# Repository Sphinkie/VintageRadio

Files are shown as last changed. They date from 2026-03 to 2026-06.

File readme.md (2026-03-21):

# VintageRadio pour Raspberry

> work in progress

## Description 

A command-line python program for RaspberryPi that plays music served by a DLNA NAS (Synology).

Faire CTRL-C pour stopper

En mode terminal: 
- n = next song
- b = play again the same song
- d = redo a DLNA server discovery
- q = quit

## Utilisation de Raspberry:

- Apairer la sortie audio avec une enceinte bluetooth si souhaité.

# Roadmap

- Bouton ON/OFF + VOLUME
- Bouton SUIVANT (right) / ENCORE (left) / STAR ME (push)
- Rotatif MODE: GENRE - ANNEE - FAV - ALEA (+ BEAT ?)
- Rotatif SOURCE : LOCAL - NAS
- Tuning GENRE: CLASSIQUES .. BLUES .. JAZZ .. FOLK .. ROCK N'ROLL .. ROCK .. CHANSONS .. MUS.MONDE .. AUTRES
- Tuning ANNEE: 1700 1800 1900  40's 50's 60's 70's 80's 2000
- Tuning FAV:   -      ☆   ☆☆   ☆☆☆   ☆☆☆☆   ☆☆☆☆☆

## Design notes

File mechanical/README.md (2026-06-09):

# Vintage Radio — Modèles 3D

Vue d'ensemble du boîtier :

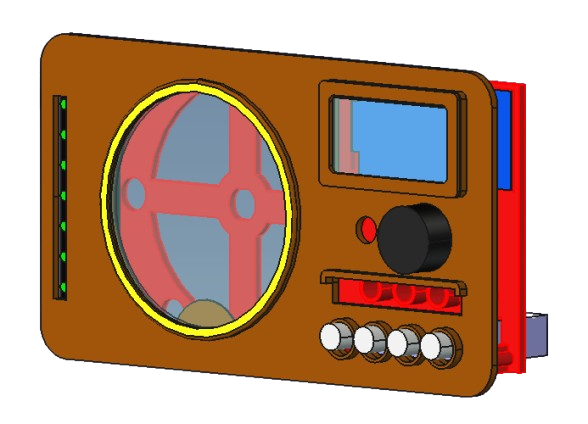
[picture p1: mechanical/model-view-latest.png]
Vue d'ensemble


---
## Conseils d'impression

- Activer le body
- Se mettre en vue ortho
- Menu: affichage -> représentation -> (3) filaire
- Menu: fichier -> Imprimer -> Préférences -> Paysage + A4 + Encre noire uniquement.  
On a alors une mise à l'échelle proche de 1:1.

## Pièces imprimables

### Face avant

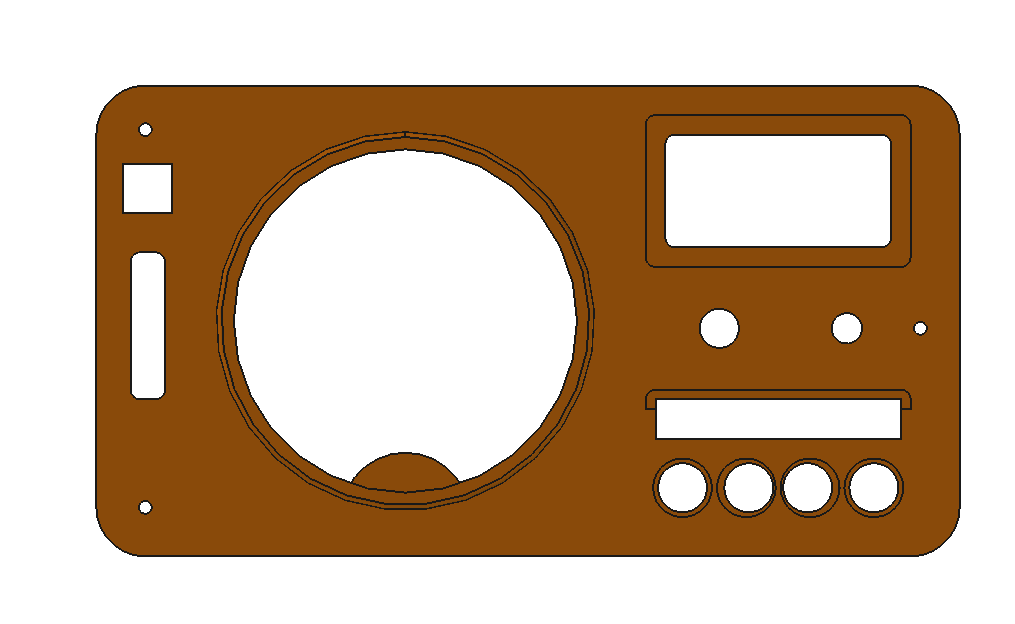
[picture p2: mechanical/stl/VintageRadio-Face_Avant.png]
Face avant


Fichier : [`VintageRadio-Face_Avant.stl`](stl/VintageRadio-Face_Avant.stl)

---

### Support

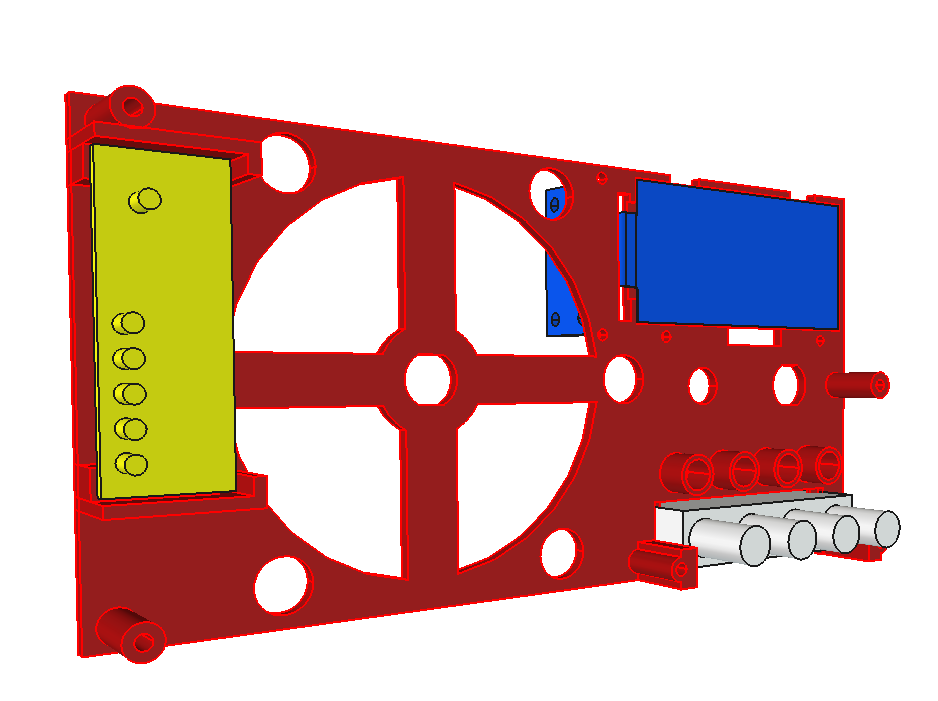
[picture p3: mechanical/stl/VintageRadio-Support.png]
Support


Fichier : [`VintageRadio-Support.stl`](stl/VintageRadio-Support.stl)

---

### Bouchon LED

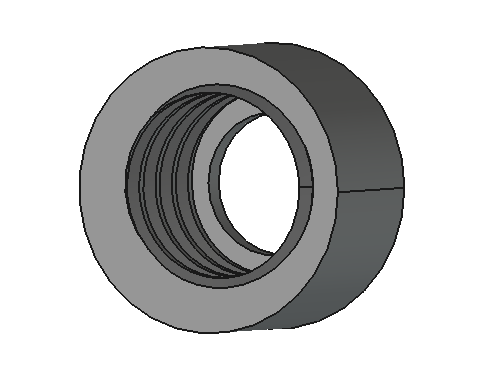
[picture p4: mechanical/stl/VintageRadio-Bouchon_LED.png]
Bouchon LED


Fichier : [`VintageRadio-Bouchon_LED.stl`](stl/VintageRadio-Bouchon_LED.stl)

---

### Rondelle LED

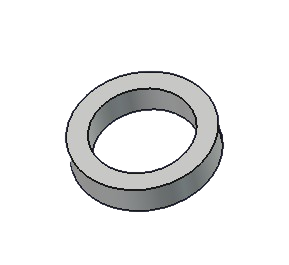
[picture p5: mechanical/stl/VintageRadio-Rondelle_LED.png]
Rondelle LED


Fichier : [`VintageRadio-Rondelle_LED.stl`](stl/VintageRadio-Rondelle_LED.stl)

---

### Support ePaper (v1)

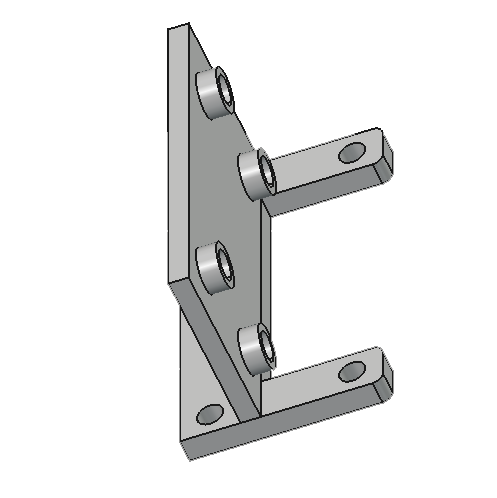
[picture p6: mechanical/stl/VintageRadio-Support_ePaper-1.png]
Support ePaper v1


Fichier : [`VintageRadio-Support_ePaper-1.stl`](stl/VintageRadio-Support_ePaper-1.stl)

---

### Support ePaper (v3)

Fichier : [`VintageRadio-Support_ePaper-3.stl`](stl/VintageRadio-Support_ePaper-3.stl)

---

## Source FreeCAD

Le fichier source est [`VintageRadio.FCStd`](cad/VintageRadio.FCStd).

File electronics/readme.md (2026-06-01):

# Vintage Radio

## Architecture générale

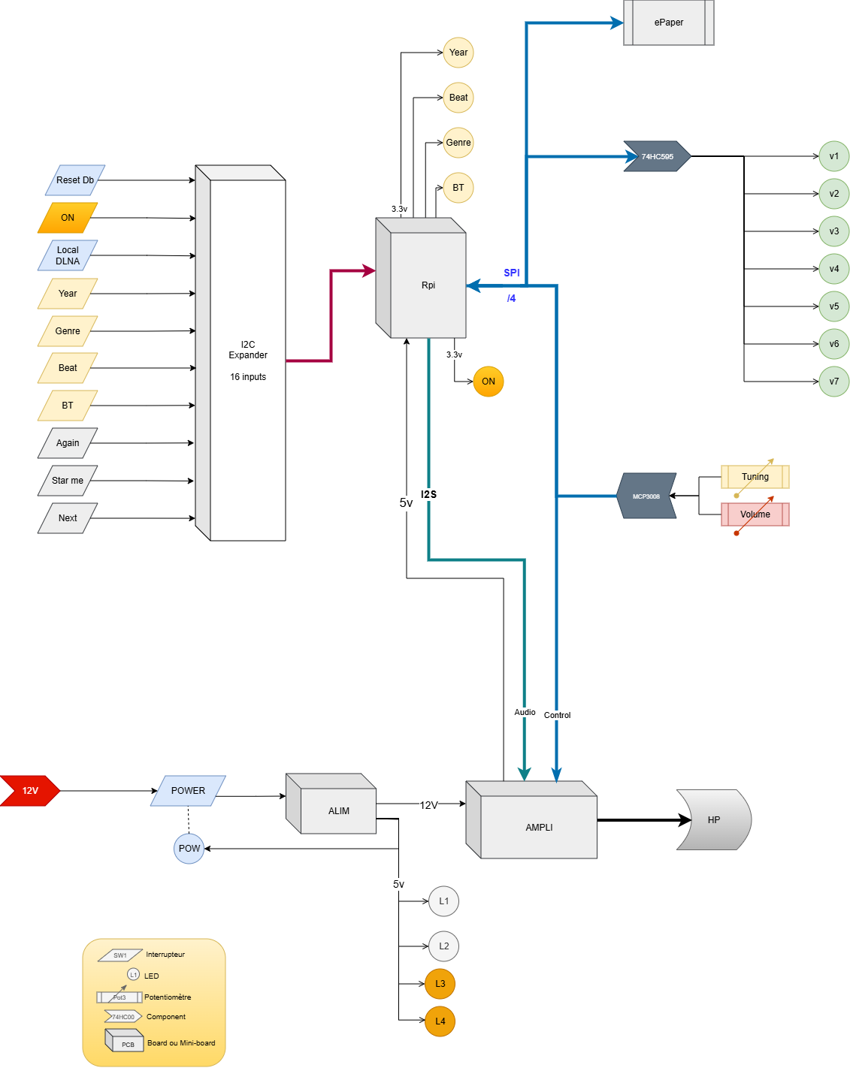
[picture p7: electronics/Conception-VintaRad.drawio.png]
Architecture générale


## Conception hardware - Les composants.

La liste des composants nécessaires est définie dans ce [Bill Of Material](Components/BillOfMaterial.md).

Le détail des calculs de résistances est dans ce [document](Resistances.md).

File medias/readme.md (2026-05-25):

# Vintage Radio

## Schéma initial

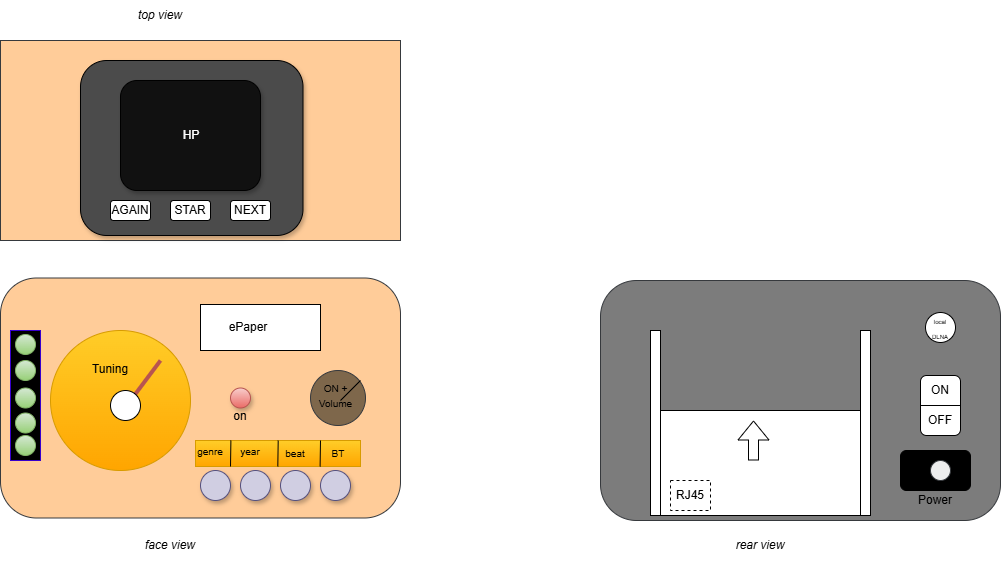
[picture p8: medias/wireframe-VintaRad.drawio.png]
projet


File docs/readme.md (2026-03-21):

# VintageRadio - Documents

Misc documents:

- [DLNA specification](UPnP-arch-DeviceArchitecture-v1.1.pdf)
- [Installation tips](tips.md)
- [Python Class Hierarchy](class_hierarchy.md)
- Python Class Diagram (drawio)
- [Python Audio Renderer Comparaison by Lumo](render-comparaison.md)
- DLNA SOAP messages samples
- [VLC options](vlc-help.txt)
- [VLC full help](vlc-full-help.txt)

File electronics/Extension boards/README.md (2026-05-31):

# Vintage Radio

## Extension boards

### Objectifs

La carte d'extension offre des connecteurs permetant de connecter directement dessus: 
- LEDs
- Boutons
- Potentionmètres

Elle contient donc les composants d'interface nécessaires, tels que résistances ou circuits intégrés.

### Contraintes

Elle se pluggue sur le connecteur 40 du Rpi + Inno de façon à accéder directement aux bus SPI, I2C, GPIO, et au +5v.

Il faut faire attention au volume de ce blioc et à son placement car le boitier n'est très grand.

Le boitier contient en particulier un HP avec un aimant assez puissant: d'où un risque de pertubation dû au champ magnitique ? A demander.

### Accessoires

D'autres minicartes (mini-boards) sont à prévoir pour supporter certains composants:

- minicarte de support de la LEDbar : connecteur 8pin

- au niveau du "Power" switch : connecteur alim + switch/Led + Res + regulateur de tension

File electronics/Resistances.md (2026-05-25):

# Vintage Radio

## Liste des résistances nécessaires

### Leds

| Ref  | Role | Tension | Piloté par | Ref | Résistance | Vf | mA | Commentaire |
| ---- | --- | --- | --- | ---- | --- | ---- | --- | --- |
|✓ L0  | Témoin logiciel | 3.3v | Rpi GPIO |✓ R0  | 120Ω | 2.1v | 10 mA  | jaune (plus vive)|
|✓ POW | Power ring | 5v | Alim board |✓ RP  | 120Ω | 3.2v | 15 mA  | bleue 16mm chrome|
|✓ L1  | backlight | 5v | Alim board |✓ R1  | 380Ω | 3.2v | 4.7 mA | white |
|✓ L2  | backlight | 5v | Alim board |✓ R2  | 380Ω | 3.2v | 4.7 mA | white |
|✓ L3  | backlight | 5v | Alim board | — | — | — | ~34 mA | amber E10 — incandescente 6V, sans résistance |
|✓ L4  | backlight | 5v | Alim board | — | — | — | ~34 mA | amber E10 — incandescente 6V, sans résistance |
|✓ V1  | value_1 | 3.3v | 74HC595 |✓ R11 | 200Ω | 2.2v | 5.5 mA | verte (moins vive)|
|✓ V2  | value_2 | 3.3v | 74HC595 |✓ R12 | 200Ω | 2.2v | 5.5 mA | verte |
|✓ V3  | value_3 | 3.3v | 74HC595 |✓ R13 | 200Ω | 2.2v | 5.5 mA | verte |
|✓ V4  | value_4 | 3.3v | 74HC595 |✓ R14 | 200Ω | 2.2v | 5.5 mA | verte |
|✓ V5  | value_5 | 3.3v | 74HC595 |✓ R15 | 200Ω | 2.2v | 5.5 mA | verte |
|✓ V6  | value_6 | 3.3v | 74HC595 |✓ R16 | 200Ω | 2.2v | 5.5 mA | verte |
|✓ V7  | value_7 | 3.3v | 74HC595 |✓ R17 | 200Ω | 2.2v | 5.5 mA | verte |
| M1 | Year | 3.3v | Rpi GPIO | R21  | 150Ω | 2.1v | 8 mA | superamber |
| M2 | Beat | 3.3v | Rpi GPIO | R22  | 150Ω | 2.1v | 8 mA | superamber |
| M3 | Genre | 3.3v | Rpi GPIO | R23  | 150Ω | 2.1v | 8 mA | superamber |
| M4 | BT | 3.3v | Rpi GPIO | R24  | 150Ω | 2.1v | 8 mA | superamber |

### Boutons poussoirs (Pull-up)

Résistances de tirage vers 3.3v sur les entrées des PCF8575 (les PCF8575 ont des pull-up internes ~100kΩ trop faibles — les 10kΩ externes assurent la robustesse).

B = Bouton poussoir.
SW = Interrupteurs à 2 positions.

| Ref | Role | Tension | Lu par  | Ref |Résistance | Commentaire |
| ----- | --- | --- | --- | ----- |--- | --- |
|✓ B1 | Year | 3.3 v | PCF8575 |✓ RS1  |10kΩ | pull-up — SIL-9 |
|✓ B2 | Genre | 3.3 v | PCF8575 |✓ RS1  |10kΩ | pull-up — SIL-9 |
|✓ B3 | Beat | 3.3 v | PCF8575 |✓ RS1  |10kΩ | pull-up — SIL-9 |
|✓ SW4  | Bluetooth  | 3.3 v | PCF8575 |✓ RS1  |10kΩ | pull-up — SIL-9 |
|✓ B5 | Again | 3.3 v | PCF8575 |✓ RS1  |10kΩ | pull-up — SIL-9 |
|✓ B6 | Star me | 3.3 v | PCF8575 |✓ RS1  |10kΩ | pull-up — SIL-9 |
|✓ B7 | Next | 3.3 v | PCF8575 |✓ RS1  |10kΩ | pull-up — SIL-9 |
|✓ B8 | Reset DB | 3.3 v | PCF8575 |✓ R31  |20kΩ | pull-up — résistance séparée |
|✓ SW9  | Local/DLNA | 3.3 v | PCF8575 |✓ R32  |20kΩ | pull-up — résistance séparée |
|✓ SW10 | Power | 12 v | -- | --  |-- | Alimente le système (avec LED séparée) |

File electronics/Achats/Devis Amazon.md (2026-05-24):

# Vintage Radio

## Devis Amazon

- Amplificateur audio (mono)
   InnoMaker RPI HiFi AMP Hat TAS5713 Amplifier Audio Module 25W Class D Power.  
   Sound Card Extension Board for Raspberry Pi 5/4/3/B+/Pi/Zero.  
   Capacitor Nichicon. Connexion SPI. Sortie sur connecteur. Réglage du gain.  
   Power supply = 12/20v.  
   Amazon 36€   
   
- 4x LED (Mode) Ambre (605nm) . Prévoir 2 à 3 cd (20 à 30 lumen) 20ma - 2.2V - Super ambre =  longueur d'onde plus profonde (~585-590 nm)

- 2x 74HC595 - Registres à décalage.

- PCF8574 (8pins) - I2C Expander.  

- 2x MCP3008 Convertisseur analogique-numerique (ADC).  

-  Potentiomètre 10kΩ - linéaire A. half-turn / single-turn.
	
- Potentiomètre 10kΩ - linéaire A - Avec interrupteur. 
   WELTRON 002045038963 WCIP20CIPS-08-60F1-10K-20%-Lin Rotary Potentiometer with Switch Mono 0.4 W 10 kΩ 1 pc(s) 
   Amazon 5.50: 

- Frais de Livraison : selon fournissseur

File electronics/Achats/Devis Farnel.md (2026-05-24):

# Vintage Radio

## Devis Farnell

- 4x LED (Mode) Ambre (605nm) . Prévoir 2 à 3 cd (20 à 30 lumen) 20ma - 2.2V - Super ambre =  longueur d'onde plus profonde (~585-590 nm)
   Farnell: _Pas trouvé_

- 2x 74HC595 - Registres à décalage.
   Farnell 1.66 € HT 

- PCF8574 (8pins) - I2C Expander.  
   Farnell 2.60 € HT

- 2x MCP3008 Convertisseur analogique-numerique (ADC).  
   Farnell 2.82 HT 
	
-  Potentiomètre 10kΩ - linéaire A.
   *half-turn / single-turn*.
	
- Potentiomètre 10kΩ - linéaire A - Avec interrupteur. 
   Farnell : indisp 

- Frais de Livraison
   Farnell 12.00 € 
   
- Montant minimum de commande
   Farnell 50.00 €

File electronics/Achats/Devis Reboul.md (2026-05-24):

# Vintage Radio

## Devis Reboul

- [ ] Amplificateur audio (mono)
	_Pas trouvé_
	
- [ ] 4x LED (Mode) Ambre (605nm) . Prévoir 2 à 3 cd (20 à 30 lumen) 20ma - 2.2V - Super ambre =  longueur d'onde plus profonde (~585-590 nm)
	_Pas trouvé_

- [ ] 2x 74HC595 - Registres à décalage.
	_Pas trouvé_

- [ ] PCF8574 (8pins) - I2C Expander.  
	_Pas trouvé_

- [ ] 2x MCP3008 Convertisseur analogique-numerique (ADC).  
	_Pas trouvé_
	
- [ ] Potentiomètre 10kΩ - linéaire A. half-turn / single-turn.
	_Pas trouvé_
	
- [ ] Potentiomètre 10kΩ - linéaire A - Avec interrupteur. 
	_Pas trouvé_

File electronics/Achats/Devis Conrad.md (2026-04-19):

# Vintage Radio

## Devis Conrad

- 4x LED (Mode) Ambre (605nm) . Prévoir 2 à 3 cd (20 à 30 lumen) 20ma - 2.2V - Super ambre =  longueur d'onde plus profonde (~585-590 nm)
   Conrad 

- 2x 74HC595 - Registres à décalage.
   Conrad 2.79 € TTC 
   Code produit : 1016774 - 62

- I2C Expander.  
   Conrad 3.79 € TTC (MCP23017 16pins) 
   Code produit : 651440 - 62

- 2x MCP3008 Convertisseur analogique-numerique (ADC).  
   Conrad 7.50 € TTC
   Code produit : 651456 - 62
	
-  Potentiomètre 10kΩ - linéaire A.
   *half-turn / single-turn*.
   Conrad 3.00 € TTC env.
	
- Potentiomètre 10kΩ - linéaire A - Avec interrupteur. 
   Conrad 7.00 € TTC env.
   Code produit : 702867 - 62
   7 possibilités: https://www.conrad.fr/fr/f/potentiometre-avec-interrupteur-1699000.html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

- Frais de Livraison
   Conrad   11.00 € 
   
> Total = env 45 €

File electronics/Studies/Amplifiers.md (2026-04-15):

# Vintage Radio

Avec un haut-parleur de 4Ω et 5W, vous avez des spécifications très courantes pour les projets DIY Raspberry Pi.  
Voici ce que cela implique pour votre choix d'amplification :

## Analyse de votre haut-parleur

Impédance (4Ω) : C'est une impédance basse. Beaucoup d'amplis "grand public" sont conçus pour 8Ω. Il faut donc un ampli capable de gérer 4Ω sans surchauffer.
Puissance (5W) : C'est une petite puissance. Un ampli de 5W à 10W par canal sera largement suffisant. Si vous mettez un ampli de 50W, vous risquez de griller le haut-parleur si vous montez le volume trop haut.
Taille (7cm) : Idéal pour une petite enceinte de bureau ou une radio vintage compacte.

## La solution idéale : Carte HAT DAC + Ampli  

C'est la solution la plus propre pour un Raspberry Pi (pas de câbles externes, qualité audio supérieure à la prise jack).  
Je vous recommande vivement l'une de ces cartes (elles supportent toutes les 4Ω) :

### Option A : JustBoom DAC HAT (Le plus simple) - discontinued.

- Puissance : 2x 5W (parfaitement adapté à votre HP).
- Impédance : Supporte 4Ω à 8Ω.
- Avantages : Très facile à installer, logiciel inclus pour le contrôle du volume via GPIO ou logiciel.
- Prix : ~35-40€.

https://www.audiophonics.fr/en/dac-and-interfaces-for-raspberry-pi/justboom-dac-hat-dac-pcm5122-for-raspberry-pi-3-pi-2-a-b-p-11602.html

### Option B : HiFiBerry DAC+ Amp (Un peu plus de puissance)

- Puissance : 2x 12W (vous aurez de la marge, attention au volume !).
- Impédance : Supporte 4Ω.
- Avantages : Son très clair, bonne réputation.
- Prix : 48€.

https://www.amazon.fr/-/en/HiFiBerry-DACPLUS-RCA-RB-Hifiberry2/dp/B0147RA2PY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

### Raspberry Pi DAC Audio IQaudio DAC+ 

- Fully HAT compliant accessory; EEPROM
- Full-HD audio - playback up to 24 bit/192 kHz
- Built-in hardware volume control (via ALSA), 2v RMS full
- Amplifier
- Prix : 27€.

https://www.amazon.fr/-/en/Raspberry-Pi-DAC-Audio-IQaudio/dp/B0BQCMYWYX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

### Adafruit MAX98357A I2S Amp Breakout (Le moins cher)

- Puissance : 3.2W (un peu juste pour 5W, mais souvent suffisant pour une petite pièce).
- Technologie : Classe D (très efficace, chauffe peu).
- Nécessite un peu plus de câblage manuel que les HAT.
- Prix : ~5€ 

https://www.adafruit.com/product/3006

### InnoMaker (Plus récentes)

- InnoMaker DAC Mini Hat PCM5122 Audio Card for Raspberry Pi 5/4/3B+/Zero 2W, 
   HiFi Sound Shield 384kHz/32bit with RCA Output and 3.5mm jack (pas on-Board)
   29€ Amazon
   
https://www.amazon.fr/-/en/InnoMaker-PCM5122-Raspberry-Shield-384kHz/dp/B0D12M8D2T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

- InnoMaker RPI HiFi AMP Hat TAS5713 Amplifier Audio Module 25W Class D Power.  
   Sound Card Extension Board for Raspberry Pi 5/4/3/B+/Pi/Zero Capacitor Nichicon.   
   Sortie sur connecteur.  
   Alternative power supply = 12/20v.  
   36€ Amazon.

https://www.amazon.fr/-/en/InnoMaker-Amplifier-Extension-Raspberry-Capacitor/dp/B07CZZ95B9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

## Comment câbler votre haut-parleur

Sur ces cartes HAT, vous trouverez généralement deux borniers (pour stéréo gauche/droite). 

### Branchement

Comme vous n'avez qu'un seul haut-parleur, connectez les deux fils de votre haut-parleur sur le bornier LEFT (Gauche) ou RIGHT (Droite).

### Configuration logicielle

Dans votre fichier de configuration audio (`/boot/config.txt` ou via `raspi-config`), vous pouvez **forcer la sortie en Mono** si vous voulez que le son sorte des deux canaux (si vous branchez le HP sur un seul, il n'y aura pas de problème, mais le son sera centré).
Ou simplement laisser VLC jouer en stéréo : le canal gauche sortira sur votre HP, le droit sera silencieux.

## Attention à l'alimentation

Ces cartes HAT tirent leur courant directement du port GPIO du Raspberry Pi.

Assurez-vous d'utiliser une alimentation USB de bonne qualité (2.5A ou 3A) pour le Pi.
Si l'alimentation est faible, vous entendrez des craquements quand la musique est forte (le voltage chute).

## Résumé du plan d'action

Achetez une DAC HAT pour ampli 5W/4Ω.  
Branchez-la sur les GPIO du Pi.    
Soudez ou vissez votre haut-parleur sur les borniers de la carte.  

Configurez le Pi pour utiliser la carte audio (`sudo raspi-config` -> `Advanced Options` -> `Audio` -> `HAT`).  
=> Dans le code Python (lib/dlna_music.py), VLC détectera automatiquement la nouvelle carte audio.

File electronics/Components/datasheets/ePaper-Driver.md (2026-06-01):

# Vintage Radio

## Waveshare 2'13 ePaper Driver HAT

### Features at a glance

- Flexible e-Paper, the display section is bendable (DON'T bend the FPC section)
- No backlight, keeps displaying last content for a long time even when power down
- Ultra low power consumption, basically power is only required for refreshing
- Comes with online development resources and manual (driver board schematic, examples for Raspberry Pi/Jetson Nano/Arduino/STM32)

### Specifications

- operating voltage 3.3V 
- display color Black/White
- interface 3-wire SPI, 4-wire SPI 
- grey scale 2
- outline dimensions 59.2 × 29.2 × 0.3 mm 
- display size 48.55 × 23.71 mm 
- full refresh time 2s
- partial refresh time 0.3s
- DOT PITCH 0.229 × 0.228 mm 
- refresh power 26.4mW(typ.)
- viewing angle > 170° 
- standby current <0.01uA (almost none)
- RESOLUTION 212 × 104 pixels

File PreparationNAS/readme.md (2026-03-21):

# Préparation du NAS

Le NAS expose des musiques MP3, via un MediaCenter compatible DLNA.

Pour un fonctionnement de base, il n'y a besoin de rien de spécial de plus.

Deux améliorations sont mises en place.  
- Normalisation du volume
- Renseignement du Beat

# Normalisation du volume

Le but est d'éviter d'écouter un morceau avec un son trop faible, suivi par un autre morceau avec un son trop fort, etc.

On utilise un utilitaire [**mp3gain**](https://mp3gain.sourceforge.net/).  

> Tired of reaching for your volume knob every time your mp3 player changes to a new song?
> MP3Gain analyzes and adjusts mp3 files so that they have the same volume.
> MP3Gain does not just do peak normalization, as many normalizers do. Instead, it does some statistical analysis to determine how loud the file actually sounds to the human ear.
> Also, the changes MP3Gain makes are completely lossless. There is no quality lost in the change because the program adjusts the mp3 file directly, without decoding and re-encoding.

Ce package va agir sur tous les fichiers mp3, sans toucher au signal audio lui-même, mais en ajoutant un tag **replayGain** qui est utilisé par VLC lorsque la musique est jouée.

## Application

Cet utilitaire peut être lancé sous Linux, mais étant donné que le Synology ne permet pas l'ajout de packages addionnels (pas de `apt install mp3gain`), on va monter le disque du NAS sous Windows, et lancer l'utilitaire en ligne de commande MS-DOS.

On l'exécute sur le répertoire parent, il va traiter recursivement les sous-répertoires.
```dos
cd M:\Music
F:\mp3gain\mp3gain.exe /r /p /c *.mp3
```

- option `-r` : Apply Track gain automatically (all files set to equal loudness)
- option `-p` : Preserve original file timestamp
- option `-c` : Ignore clipping warning when applying gain
ou  
- option `-s c` : Only check stored tag info (no other processing)

> TODO : le faire sur les nouveaux morceaux, au fur et à mesure des ajouts.

# Détection du rythme (Beat Per Minute)

Ce tag **BPM** (Beat Per Minute) permet de distinguer les morceaux calmes des morceaux dynamiques.

## Méthode 1

Utilisation de l'utilitaire FREEWARE [**MixMeister BMP Analyzer**](https://www.mixmeister.com) v1.0.  
*Disponible dans `/bin`*

- Installer **MixMeister BMP Analyzer** (pour Windows 10 - 32bits). 
- Lancer l'application. 
- Sélectionner le répertoire des musiques à analyser. 
- Attendre qu'il ait fini son analyse. 
- Le tag **BPM** est alors automatiquement ajouté à chaque MP3 *(la date du fichier est modifiée)*.

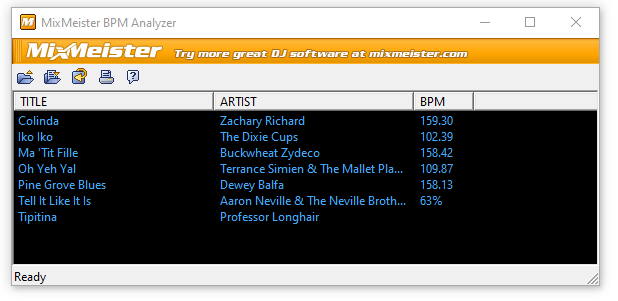
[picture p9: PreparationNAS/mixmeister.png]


## Méthode 2

Utilisation de l'utilitaire FREEWARE [**PistonSoft BMP Detector**](https://www.pistonsoft.com/bpm-detector.html).  
*Disponible dans `/bin`*

- Installer l'utilitaire **Pistonsoft BPM Detector** (pour Windows Vista - 32bits - 2007). 
- Lancer l'application. 
- Sélectionner le répertoire des musiques à analyser. 
- Attendre qu'il ait fini son analyse. 
- Sauvegarder.
 
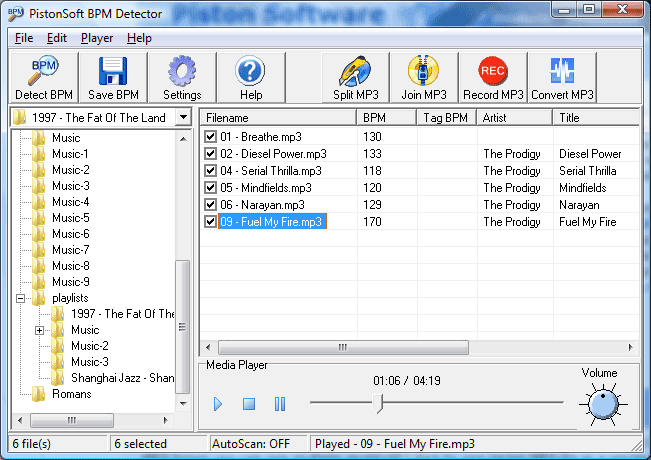
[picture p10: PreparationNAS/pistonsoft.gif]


Résultats parfois inadéquats...

## Méthode 3

Script python trouvé sur GitHub : [the-BPM-detector](https://github.com/scaperot/the-BPM-detector-python) par Scaperot.

Non essayé.

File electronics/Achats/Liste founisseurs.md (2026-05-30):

# Liste de fournisseurs de materiels électronique

| Fournisseur | Achalandage | Commande minimale | Frais de Port | Commentaire |
| --- |--- |--- |--- |--- |
| Farnel | Très complet | oui | élevé | ok si gros appro à faire - Attention prix HT|
| Mousser | | | | Pas essayé |
| Conrad | très complet | ? | 11€ | Assez cher dans l'ensemble |
| Lextronix | faible | ? | 8€ | Pas trouvé ce dont j'avais besoin |
| Gotronic | complet | non | 4€ | GUI très claire |
| ExpTech | | | | Pas essayé |
| MC Hobby | Faible choix | | | Pas trouvé ce dont j'avais besoin |
| FR AURORA | | | | Pas essayé |
| E44 | | | masqués dans GUI | catalogue cher |
| RS-Particuliers.com | | | | GUI ultra lente |
| banggood (chinois) | Correct mais par grosse quantité (env. 100) | | | inondé de spams ensuite |
| Amazon | Correct mais par quantité (env. 10) | non | variable 4€ | peu de livraison gratuite sur l'ELN |

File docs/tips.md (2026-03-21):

# Vintage Radio - Tips

## Q&A - Problématiques rencontrées

### pynput requires a graphical display (X server) to capture keyboard input

- On peut remplacer `pyinput` par `termios` and `tty`. OK en mode console, mais ne fonctionne plus sous Windows.
- Il faut implémenter du cross-platform.
   - option 1 : conditionnal imports (Uses only built-in Python modules)
   - option 2 : librairie cross-platfom `readchar`
   Lumo recommande l'option 1 dans notre cas.

### PyCharm ne redirige pas les touches vers l'app

Aller dans le menu `Run -> Edit Configuration -> Modify options` et cocher **Emulate terminal in output console**.

### Raspberry: pas d'echo sur le terminal SSH

Tapez ceci pour rétablir le mode normal sur le terminal bloqué:

```
stty sane
```

## Choix du module de sortie son

- Sous Raspberry `--aout {any,pulse,alsa,adummy,amem,afile,none}`
- sous Windows `--aout={any,mmdevice,directsound,waveout,amem,afile,adummy,none}`

Lumo recommande `mmdevice` pour Windows et `alsa` pour Raspberry.

Test sur Raspberry avec clvc:
- directsound : ok
- mmdevice : ok
- any : ok
- pulse : ok
- alsa: **no sound**

En tant que daemon:
- alsa : vlcpulse audio output error: PulseAudio server connection failure: Connection refused
- pulse : idem
- mmdevice : idem
- any : idem

### Liste des périphériques matériels PLAYBACK 

```shell
$ aplay -l
 
**** Liste des périphériques matériels PLAYBACK ****
carte 0 : Headphones [bcm2835 Headphones], périphérique 0 : bcm2835 Headphones [bcm2835 Headphones]
  Sous-périphériques : 8/8
  Sous-périphérique #0 : subdevice #0
  Sous-périphérique #1 : subdevice #1
  Sous-périphérique #2 : subdevice #2
  Sous-périphérique #3 : subdevice #3
  Sous-périphérique #4 : subdevice #4
  Sous-périphérique #5 : subdevice #5
  Sous-périphérique #6 : subdevice #6
  Sous-périphérique #7 : subdevice #7
carte 1 : vc4hdmi [vc4-hdmi], périphérique 0 : MAI PCM i2s-hifi-0 [MAI PCM i2s-hifi-0]
  Sous-périphériques : 1/1
  Sous-périphérique #0 : subdevice #0
```

### Liste des périphériques matériels PULSE

Cette commande done la liste des sortie audio connues (**bluez** = bluetooth)

```shell
$ pactl list short sinks
# 56      alsa_output.platform-3f00b840.mailbox.stereo-fallback   PipeWire        s16le 2ch 48000Hz       SUSPENDED
# 118     bluez_output.20_18_5B_06_45_B0.1        PipeWire        s16le 2ch 44100Hz       SUSPENDED

# Obtenir la liste détaillée
$ pactl list sinks

# Obtenir des détails sur l'équipement bluetooth connecté (dont l'adresse MAC)
$ bluetoothctl info
```

### Configurer PipeWire pour la connexion automatique à l'enceinte JLB

Une fois que l'on a obtenu l'adreses MAC du périphérique Bluetooth, on peut le declarer auprès de **pipewire** pour qu'il puisse l'utilser comme sortie audio.

```shell
# Assignation
$ pactl set-default-sink bluez_output.20_18_5B_06_45_B0.1
# Unmute
$ pactl set-sink-mute bluez_output.20_18_5B_06_45_B0.1 0
# Volume 80%
$ pactl set-sink-volume bluez_output.20_18_5B_06_45_B0.1 80%
# Voir le résultat
$ pactl info
 Chaîne du serveur : /run/user/1000/pulse/native
 Version du protocole de bibliothèque : 35
 Version du protocole du serveur : 35
 Local : oui
 Index client : 138
 Tile Size : 65472
 Nom d’utilisateur : pi
 Nom d’hôte : Raspberry
 Nom du serveur : PulseAudio (on PipeWire 1.4.2)
 Version du serveur : 15.0.0
 Spécification d’échantillon par défaut : float32le 2ch 48000Hz
 Plan de canaux par défaut : front-left,front-right
 Destination par défaut : bluez_output.20_18_5B_06_45_B0.1
 Source par défaut : bluez_output.20_18_5B_06_45_B0.1.monitor
 Cookie : 3b8b:f4f4
```

Note : voir !484 et svtes pour Alsa

### Create the PipeWire Configuration File

Create the permanent PipeWire configuration for your Bluetooth speaker. 
This will ensure the sink preference persists across reboots and is more robust than the runtime pactl command.

> DO NOT USE: pas trouvé la cause, mais en partique, la présence de ce fichier *empèche* la connection à l'enceinte bluetooth.

```shell
sudo mkdir -p /etc/pipewire/pipewire.conf.d
sudo nano /etc/pipewire/pipewire.conf.d/99-default-sink.conf
```

Add This Content.

```
# Default audio sink configuration for VintageRadio
# Created: 2026-03-21

context.properties = {
    # Set the default audio sink to your Bluetooth speaker
    # This persists across reboots
    default.audio.sink = bluez_output.20_18_5B_06_45_B0.1
    
    # Optional: Set default sample rate (matches your speaker capability)
    default.clock.rate = 44100
    
    # Optional: Prevent automatic suspension when idle
    # default.clock.quantum = 1024
}

context.modules = [
    # Ensure Bluetooth modules are loaded
    { name = libpipewire-module-bluez5
      args = {
        bluez5.enable = true
        bluez5.enable-sbc-xq = true
        bluez5.enable-msbc = true
        bluez5.enable-hw-volume = true
        bluez5.headset-roles = [ hsp_hs hsp_ag hfp_hf hfp_ag a2dp_sink a2dp_source ]
      }
    }
]
```

Restart PipeWire Services.

```shell
# Restart PipeWire and PulseAudio compatibility layer
systemctl --user restart pipewire pipewire-pulse wireplumber
# Or with sudo if the services are running at system level
# sudo systemctl restart pipewire pipewire-pulse wireplumber

# Wait a moment for services to stabilize
sleep 3

# Verify the default sink
pactl info | grep "Default Sink"
# You should see:
# Default Sink: bluez_output.20_18_5B_06_45_B0.1

sudo systemctl restart vintageradio.service
```

### If You Change Speakers Later

If you replace your JBL Flip 5 with a different Bluetooth speaker:

```shell
# 1. Find the new sink name
pactl list short sinks | grep bluez

# 2. Edit the configuration
sudo nano /etc/pipewire/pipewire.conf.d/99-default-sink.conf

# 3. Update the sink name
# Change: default.audio.sink = bluez_output.NEW_MAC_ADDRESS.1

# 4. Restart services
systemctl restart pipewire pipewire-pulse
# Or with sudo if the services are running at system level
# sudo systemctl restart pipewire pipewire-pulse

```

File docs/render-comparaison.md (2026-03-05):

# Render Python libs comparison by Lumo

## playsound – what it actually does

**playsound** is a very thin wrapper around the operating-system’s native audio player.

- On Windows it calls `winsound.PlaySound` (which only supports WAV) or falls back to `PowerShell/wmplayer` for MP3.
- On macOS it invokes `afplay`.
- On Linux it tries `aplay`, `paplay`, or `ffplay` if they are installed.

Because the library delegates the decoding and playback to whatever player the OS provides, the audio quality you hear is exactly the quality of that underlying player.  
`playsound` itself does not apply any DSP, equalisation, or resampling, so there is no “good-vs-bad” quality difference inside the library – it’s entirely dependent on the system’s codec implementation.

## Pros

✅Feature
- Simplicity - One-line call: `playsound('song.mp3')`.
- No external dependencies (apart from the OS player).
- Works for quick scripts or prototypes.

## Cons

❌Limitation
- No volume control, pause/resume, or event callbacks.
- Blocking call – the thread is held until the file finishes. 
- Relies on whatever codecs the OS ships; older Windows versions may fall back to low-quality decoders.
- No cross-platform consistency (different players behave slightly differently).

## Better-suited alternatives for high-quality, controllable MP3 playback in Python

| Library | Quality / Features | Typical Install Command | When to choose it | 
|---|---|---|---|
| pygame.mixer (part of pygame) | Uses SDL’s mixer, which decodes MP3 via libmad/ffmpeg; solid 44.1kHz–16-bit output. Supports volume, pause, stop, looping, and non-blocking playback. | pip install pygame | You already need a game-style loop or want simple real-time control. |
| vlc (python-vlc) | Thin binding to libVLC – the same engine behind the VLC desktop player. Handles every common codec, offers precise seeking, volume, playlists, and hardware-accelerated decoding when available. | pip install python-vlc (requires VLC installed on the system) | You need robust codec support, streaming, or advanced controls. | 
| pydub + simpleaudio | pydub loads/filters audio (uses ffmpeg under the hood); simpleaudio plays the raw PCM buffer. Gives you full access to the waveform, can change sample rate, apply effects, and play asynchronously. | pip install pydub simpleaudio (ffmpeg must be on PATH) | You want to manipulate the audio (trim, fade, concatenate) before playing. | 
| sounddevice | Directly streams NumPy arrays to the sound card via PortAudio. Very low latency, great for synthesis or processing pipelines. | pip install sounddevice | You generate audio programmatically or need sample-accurate timing. |
| playsound-async (fork) | Same API as playsound but runs playback in a background thread, letting your script continue. Still relies on the OS player for decoding. | pip install playsound-async | You like the one-liner style but need non-blocking behaviour. |
| ffpyplayer | FFmpeg-based player with Python bindings; supports video too. Good for custom media pipelines. | pip install ffpyplayer | You already use FFmpeg elsewhere and want a unified interface. |
| pyglet.media | Part of the pyglet multimedia library; uses OpenAL/AVbin for decoding. Handles MP3, OGG, WAV, etc., with volume and looping. | pip install pyglet | You are building a GUI/game with pyglet already. |

## Quick example with python-vlc (high-quality, non-blocking)

```python
import vlc
import time

# Create a VLC instance and media player
player = vlc.MediaPlayer("song.mp3")

# Start playback (returns immediately)
player.play()

# Optional: wait until the track ends (or do other work)
while player.get_state() != vlc.State.Ended:
    time.sleep(0.5)          # poll every half-second
```

If `import vlc` fails: 
- check that the installed VLC is 64bits or 32bits, the same as your Python interpreter.
- check that `libvlc.dll` is accessible by the Python interpreter:
  - Temporary (only for the current PowerShell session)
    `$env:PATH += ";C:\Program Files\VideoLAN\VLC" `
  - permanently via System→Advanced system settings → Environment Variables → edit Path  

## Quick example with pygame.mixer

```python
import pygame

pygame.mixer.init()               # initializes the audio subsystem
pygame.mixer.music.load("song.mp3")
pygame.mixer.music.set_volume(0.8)   # 0.0 … 1.0
pygame.mixer.music.play()

# Keep the script alive while music plays
while pygame.mixer.music.get_busy():
    pygame.time.Clock().tick(30)   # 30-fps loop
```
	
Both of these libraries decode the MP3 themselves (via `ffmpeg/libVLC` or `SDL_mixer`), so the playback quality is consistent across platforms and independent of the OS’s built-in decoder.

## Which one should you pick?

| Goal | Recommended library | 
|---|---|
| Just a quick “play this file” in a throw-away script | playsound (if you accept blocking) or playsound-async. | 
| Need volume/pause/stop and reliable cross-platform quality | pygame.mixer or python-vlc. | 
| Want to edit/concatenate audio before playing | pydub+simpleaudio. | 
| Real-time synthesis or low-latency playback | sounddevice (or pygame if you already have a game loop). | 
| Already using VLC or need advanced codec support | python-vlc. | 
| Building a GUI/game with its own event loop | pyglet.media or pygame. | 

## Bottom line

playsound will play MP3s at whatever quality the host OS’s default player provides, but it gives you no control and blocks your program.
For consistent, high-quality playback with runtime control, the most straightforward drop-in replacements are pygame.mixer (lightweight, pure Python) or python-vlc (full-featured, uses the battle-tested VLC engine). Choose the one that matches the rest of your project’s stack and the level of control you need.

## playsound-async 

Installing the package:
```
pip install playsound-async 
```
**playsound-async** works on Windows, macOS and Linux.  
It uses the same underlying OS player as playsound but runs the playback in a background thread, so your script can continue doing other work while the audio is playing.

## Minimal example – fire-and-forget playback with playsound-async

```python
from playsound_async import playsound
import time

# -------------------------------------------------
# Start playback (non-blocking)
# -------------------------------------------------
playsound("example.mp3")          # returns immediately

# -------------------------------------------------
# Do something else while the file plays
# -------------------------------------------------
for i in range(5):
    print(f"working … ({i+1}/5)")
    time.sleep(1)                # simulate other work

print("Done – the MP3 may still be playing in the background.")
```

Running the script prints the progress messages every second while the MP3 continues to play in the background. 
When the script exits, the daemon thread is terminated, so the sound stops automatically.

### Controlling the playback (optional)

`playsound-async` returns a `PlayHandle` object that lets you stop the sound early if you need to:

```python
from playsound_async import playsound
import time

handle = playsound("example.mp3")   # start async playback
time.sleep(3)                      # let it play for a bit
handle.stop()                      # stop immediately
print("Playback stopped manually.")
```

`handle.stop()` sends a termination request to the underlying OS player.  
The handle also exposes `is_playing()` (True while the sound is still active).

### Things to keep in mind

| Aspect | Detail |
|---|---|
| File format | Any format the OS can play (MP3, WAV, AAC, …). | 
| Blocking vs. non-blocking | The call itself never blocks; the returned handle lets you intervene. | 
| Thread safety | The playback runs in a daemon thread, so it won’t prevent the interpreter from exiting. | 
| Dependencies | No extra binaries; it relies on the OS-provided player (same as playsound). | 

That’s all you need to get quick, asynchronous MP3 playback with playsound-async.  
Happy coding!

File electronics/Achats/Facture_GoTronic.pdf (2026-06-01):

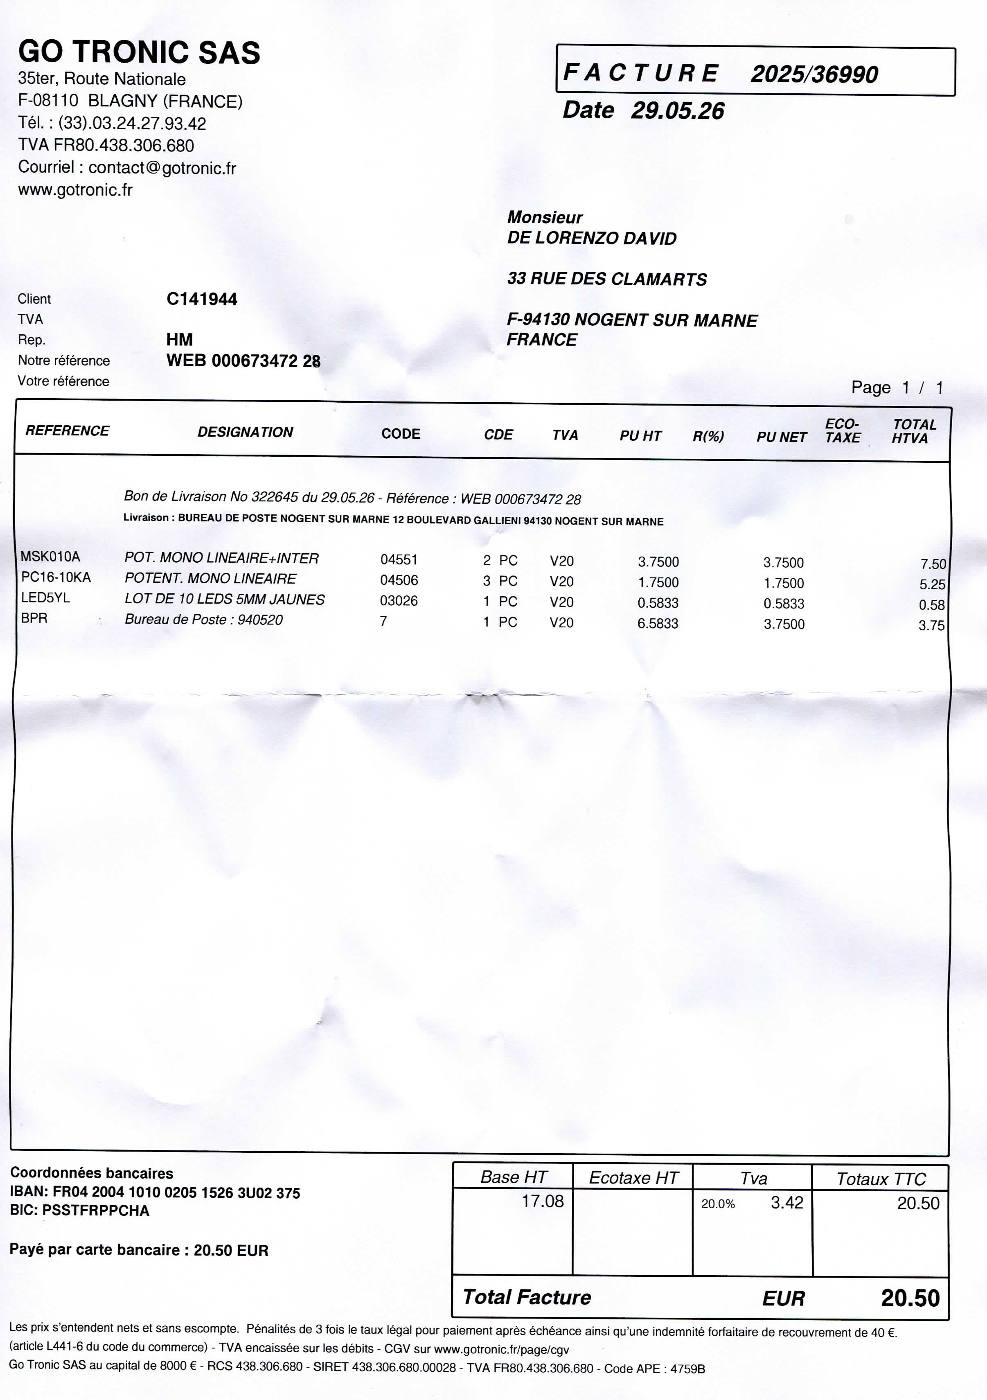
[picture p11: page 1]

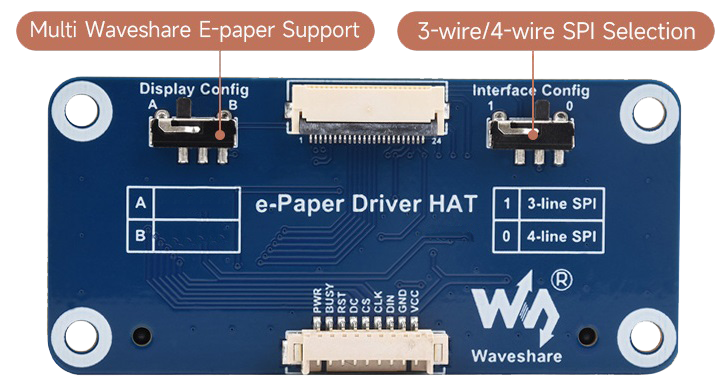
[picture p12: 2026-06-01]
electronics/Components/images/13.3inch-ePaper-HAT-interco.png

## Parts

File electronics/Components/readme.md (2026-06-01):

# Vintage Radio

## Component

Les différents composants électroniques du projet.

[Bill Of Material](BillOfMaterial.md)

## Architecture simplifiée

Architecture simplifiée

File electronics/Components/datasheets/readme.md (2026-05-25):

# Vintage Radio

## Component datasheets

Datasheet des différents composants.

| Composant | Document |
| --- | --- |
| InnoMaker TAS5713 | [Pinout](InnoMaker_TAS5713_pinout.jpg) — [Board map](InnoMaker_TAS5713_map.jpg) |
| LED superambre | [Datasheet](<LED superambre 2861556.pdf>) |
| MCP3008 (ADC) | [Notes](MCP3008-Converter.md) |
| PCF8575 (I2C Expander) | [Datasheet](PCF8575.md) — [Câblage boutons](PCF8575-wiring.md) |
| SN74HCS595 (Shift register) | [Pinout](SN74HCS595_Pinout.png) |

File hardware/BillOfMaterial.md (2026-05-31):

# Vintage Radio

## Bill Of Material

### Outputs
   
- [x] Ecran ePaper 2.13" - 5cm x 2.5cm - 212 x 104 px - Avec Driver HAT et bus SPI.  
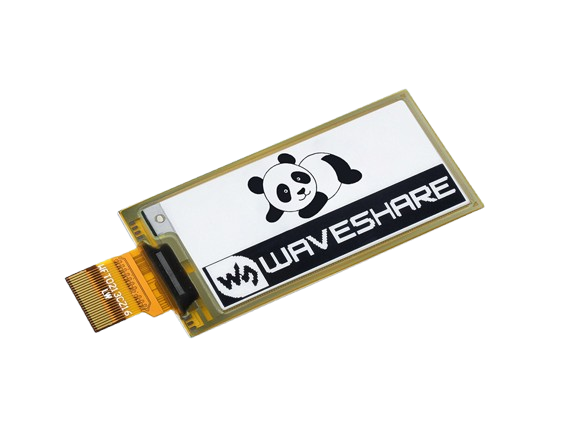
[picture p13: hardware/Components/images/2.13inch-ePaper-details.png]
ePaper
  
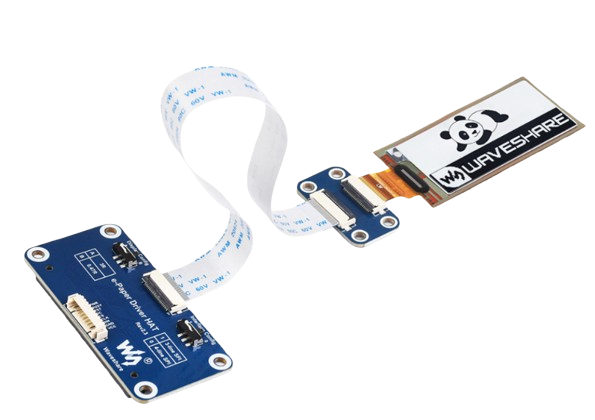
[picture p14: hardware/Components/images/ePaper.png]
ePaper with Driver HAT
    
  [Sizes](Components/datasheets/ePaper-Driver-HAT-size.png) — [Features](Components/datasheets/ePaper-Driver-HAT-features.png) — [SPI Control](Components/datasheets/ePaper-Driver-HAT-SPIcontrol.png)

- [x] Haut parleur - 4Ω - 5 W - Diamètre 7cm

- [x] 1x LED Jaune. _Ref: L0_  
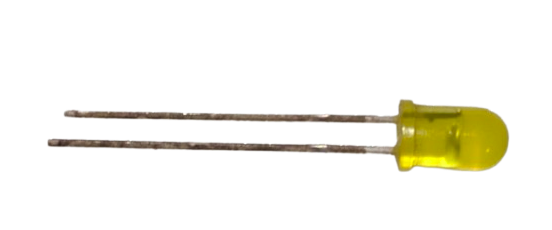
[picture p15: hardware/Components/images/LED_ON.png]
LED jaune L0
  
- [x] 1x Résistance 120Ω (sous 3.3v — Vf=2.1v, 10mA). _Ref: R0_

- [ ] 4x LEDs oranges (Modes). Prévoir 2 à 3 cd (20 à 30 lumen). _Ref: M1 M2 M3 M4_  
  [Datasheet](<Components/datasheets/LED superambre 2861556.pdf>)
- [ ] 4x Résistance 150Ω (sous 3.3v — Vf=2.1v, 8mA/led). _Ref: R21 R22 R23 R24_

- [x] 1x LED bar (7 Leds vertes) Vf=2.2v - 20mA. _Ref: V1 V2 V3 V4 V5 V6 V7_
- [x] 7x Résistance 200Ω (sous 3.3v — Vf=2.2v, 5.5mA/led). _Ref: R11 R12 R13 R14 R15 R16 R17_  
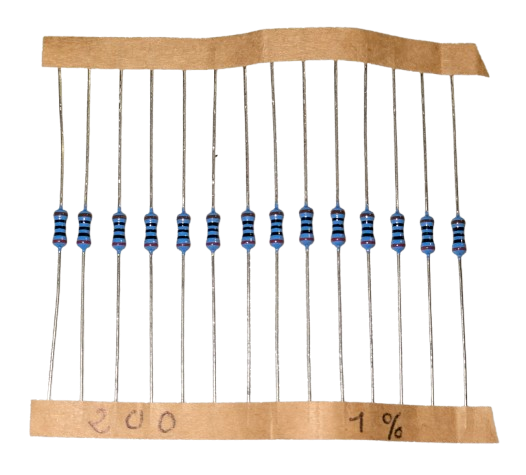
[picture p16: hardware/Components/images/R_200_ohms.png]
Résistances 200Ω
  

- [x] 2x LEDs E10 (Eclairage tuning). _Ref: L3 L4_   
  Ampoule incandescente 6V/0.25W — sans résistance (filament auto-limitant, ~34mA sous 5v).  
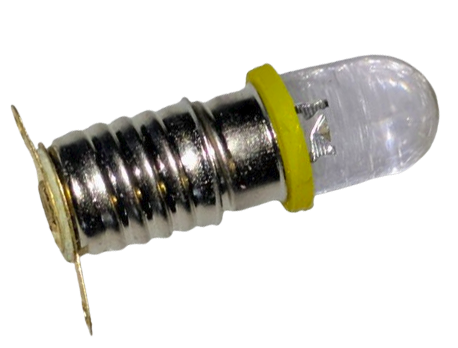
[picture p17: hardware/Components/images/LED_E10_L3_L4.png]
LED E10 amber L3 L4
  

- [x] 2x LEDs blanches (Eclairage ePaper). _Ref: L1 L2_  
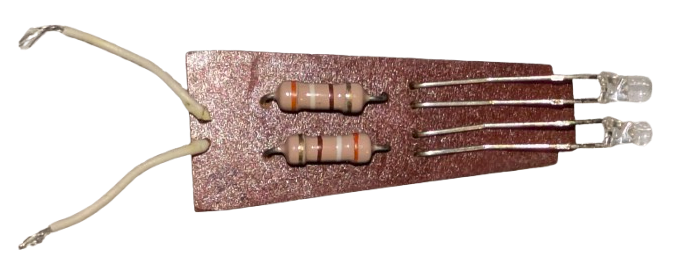
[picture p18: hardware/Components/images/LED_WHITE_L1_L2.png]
LED blanche L1 L2
  
- [x] 2x Résistance 380Ω (sous 5v — Vf=3.2v - 4.7mA/led). _Ref: R1 R2_

### Inputs

- [x] 4x PushButton (Year / Genre / Beat / Bluetooth). _Ref: B1 B2 B3 SW4_  
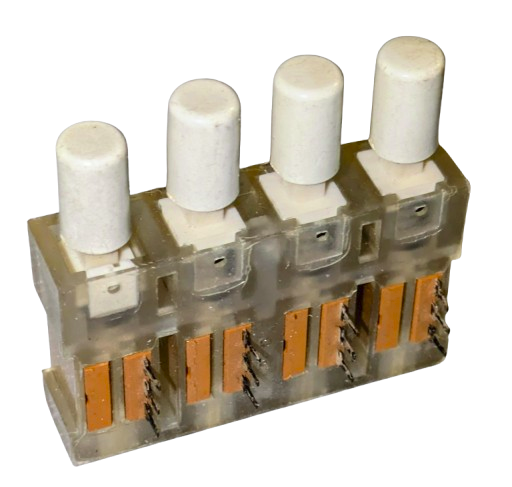
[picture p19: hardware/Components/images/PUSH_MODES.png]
PushButton modes
  
- [x] 3x PushButton (Again / Star me / Next). _Ref: B5 B6 B7_  
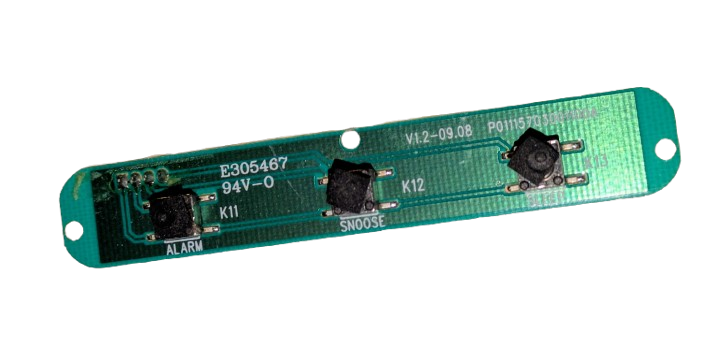
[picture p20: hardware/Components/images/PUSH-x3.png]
PushButton x3
  
- [x] 8x Résistance pull-up 10kΩ SIL-9 (7 utilisées + 1 spare). _Ref: RS1_  
  SIL-9 10k

- [x] 1x micro PushButton (Reset database) - En face arrière. _Ref: B8_  
  PushButton Reset DB
- [x] 1x Résistance 20kΩ pull-up. _Ref: R31_

- [x] 1x Switch Button (Local files/DLNA) - En face arrière. _Ref: SW9_  
  Switch Local/DLNA
- [x] 1x Résistance 20kΩ pull-up. _Ref: R32_

- [x] 1x Power Button (incl. LED) - En face arrière. Bouton 16mm chrome, anneau LED bleue. _Ref: SW10_  
  Power Button
- [x] 1x Résistance 120Ω (LED ring bleue, sous 5v — Vf=3.2v, 15mA). _Ref: RP_

### Composants

- [x] Amplificateur audio (mono)
   InnoMaker RPI HiFi AMP Hat TAS5713 Amplifier Audio Module 25W Class D Power.  
   Sound Card Extension Board for Raspberry Pi 5/4/3/B+/Pi/Zero.  
   Capacitor Nichicon. Connexion SPI. Sortie sur connecteur. Réglage du gain.  
   Power supply = 12/20v.  
   36€ Amazon.  
  InnoMaker TAS5713
  InnoMaker TAS5713 HAT  
  [Pinout](Components/datasheets/InnoMaker_TAS5713_pinout.jpg) — [Board map](Components/datasheets/InnoMaker_TAS5713_map.jpg)

- [x] 74HC595 Registres à décalage pour controle des LEDs. Format DIP-16.   
   Amazon 9€ (les 10).  
  74HC595  
  [Pinout](Components/datasheets/SN74HCS595_Pinout.png)

- [x] PCF8575 (16-Inputs) I2C Expander pour controle des Pushbutton. Format miniboard.   
   Amazon 7€ (les 2)
  PCF8575 front 
  PCF8575 back  
  [Datasheet](Components/datasheets/PCF8575.md)

- [x] MCP3008 Convertisseur analogique-numerique Adafruit (ADC).  Format DIP-16.  
   8 canaux, 10 bits (1024 valeurs) - Connexion SPI. Lib Python: spidev.    
   Amazon 22€ (les 2).  
  MCP3008  
  [Datasheet](Components/datasheets/MCP3008-Converter.md)
	
- [ ] Potentiomètre 10kΩ - linéaire A.  
   Trop difficile à trouver en 180° (*half-turn*) => on prend un *single-turn*.  
	
- [ ] Potentiomètre 10kΩ - linéaire A - Avec interrupteur.  
   WELTRON 002045038963 WCIP20CIPS-08-60F1-10K-20%-Lin Rotary Potentiometer with Switch Mono 0.4 W 10 kΩ 1 pc(s) 
   Amazon 5.50€

- [ ] Ecran plexi

### Récapitulatif des résistances

  | Valeur     | Qté       | Refs                        | Usage                       | En stock |
  | ---------- | --------- | --------------------------- | --------------------------- | -------- |
  | 120Ω       | 2         | R0, RP                      | L0 (témoin) + POW (ring)    | oui      |
  | 150Ω       | 4         | R21 R22 R23 R24             | M1–M4 (mode superamber)     |          |
  | 200Ω       | 7         | R11 à R17                   | V1–V7 (LED bar rating)      | oui      |
  | 380Ω       | 2         | R1 R2                       | L1 L2 — backlight ePaper    | oui      |
  | 10kΩ SIL-9 | 1 boîtier | RS1                         | B1–B7 (7 pull-ups, 1 spare) | oui      |
  | 20kΩ       | 2         | R31 R32                     | B8 Reset + SW9 Local/DLNA   | oui      |

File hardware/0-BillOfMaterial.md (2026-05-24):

# Vintage Radio

## Bill Of Material

### Outputs
   
- [x] Ecran ePaper
   Deux modèles à disposition dan le stock:
   - ePaper 2.13" - 5cm x 2.5xm - SPI - 250 x 122
   - ePaper 2.9" - 3cm x 6.8cm - SPI - 296 x 128
   Connexion SPI.

- [x] Haut parleur - 4Ω - 5 W - Diamètre 7cm

- [x] 1x LED Jaune (status "ON"). 
- [x] 1x Resistance 150Ω (sous 3.3v)

- [ ] 4x LED (Mode) Ambre. Prévoir 2 à 3 cd (20 à 30 lumen)
- [x] 4x Résistance 150Ω (sous 3.3v — Vf=2.1v, 8mA/led)

- [x] 1x LED bar (Affichage du rating) (7 Leds vertes) 2.2v 20mA
- [x] 7x Résistance 150Ω (sous 3.3v — Vf=2.2v, 7.3mA/led, 51mA total — dans la limite 74HC595 70mA max)

- [x] 2x LED E10 (Eclairage tuning) : L3 + L4
- [x] 2x Résistance 150Ω (sous 5v — Vf=2.0v, 20mA/led)

- [x] 1x LED (Eclairage ePaper) - Double blanche L1 + L2 (nécessite 5v avec résistances 380Ω).  

### Inputs

- [x] 3x PushButton (Again / Star me / Next)
- [x] 4x PushButton (Genre / Year / Beat / Bluetooth).   
- [x] 8x Résistance pour PushButton (10kΩ) SIL-9

- [x] 1x micro PushButton (Reset database) - En face arrière.  
- [x] 1x Résistance 10k

- [x] 1x Switch Button (Local files/DLNA) - En face arrière.
- [x] 1x Résistance 10k

- [x] 1x Power Button (incl. LED) - En face arrière. Bouton 16mm chrome, anneau LED bleue.
- [x] 1x Résistance 120Ω (LED ring bleue, sous 5v — Vf=3.2v, 15mA)

### Composants

- [x] Amplificateur audio (mono)
   InnoMaker RPI HiFi AMP Hat TAS5713 Amplifier Audio Module 25W Class D Power.  
   Sound Card Extension Board for Raspberry Pi 5/4/3/B+/Pi/Zero.  
   Capacitor Nichicon. Connexion SPI. Sortie sur connecteur. Réglage du gain.  
   Power supply = 12/20v.  
   36€ Amazon.  
   
- [x] 2x 74HC595 Registres à décalage pour controle des LEDs. Format DIP-16.  
   Amazon 9€ (les 10)

- [x] PCF8574 (8pins) I2C Expander pour controle des Pushbutton. Format miniboard.  
   Amazon 7€ (les 2)

- [x] MCP3008 Convertisseur analogique-numerique Adafruit (ADC).  Format DIP-16.
   8 canaux, 10 bits (1024 valeurs) - Connexion SPI. Lib Python: spidev.   
   Amazon 22€ (les 2)
	
- [ ] Potentiomètre 10kΩ - linéaire A.  
   Trop difficile à trouver en 180° (*half-turn*) => on prend un *single-turn*.  
	
- [ ] Potentiomètre 10kΩ - linéaire A - Avec interrupteur.  
   WELTRON 002045038963 WCIP20CIPS-08-60F1-10K-20%-Lin Rotary Potentiometer with Switch Mono 0.4 W 10 kΩ 1 pc(s) 
   Amazon 5.50: 

- [ ] Ecran plexi

### Récapitulatif des résistances

  | Valeur     | Qté       | Usage                          | En stock | 
  | ---------- | --------- | ------------------------------ | -------- |
  | 120Ω       | 1         | P — LED bleue power ring       |  |
  | 150Ω       | 14        | On + L3 + L4 + V1–V7 + M1–M4   |  |
  | 380Ω       | 2         | L1 + L2 — backlight ePaper     | oui      |
  | 10kΩ SIL-9 | 1 boîtier | B1–B7 (7 pull-ups, 1 spare)    | oui      |
  | 10kΩ       | 2         | B8 Reset + SW9 Local/DLNA      | oui      |

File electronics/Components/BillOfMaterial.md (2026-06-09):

# Vintage Radio

## Bill Of Material

### Outputs
   
- [x] Ecran ePaper 2.13" flexible (Ref Waweshare SKU 14986) - 5cm x 2.5cm - 212 x 104 px. Avec Driver HAT (ref Waveshare RRX)(avec bus SPI).  
  ePaper
  ePaper with Driver HAT  
  [Sizes](datasheets/ePaper-Driver-HAT-size.png) — [Features](datasheets/ePaper-Driver-HAT-features.png) — [SPI Control](datasheets/ePaper-Driver-HAT-SPIcontrol.png) — [Description](datasheets/ePaper-Driver.md)

- [x] Haut parleur - 4Ω - 5 W - Diamètre 7cm

- [x] 1x LED Jaune (pour le statut ON). _Ref: L0_ 
  LED jaune L0
  
- [x] 1x Résistance 120Ω (sous 3.3v — Vf=2.1v, 10mA). _Ref: R0_

- [x] 2x LEDs blanches (Eclairage ePaper). _Ref: L1 L2_  
  LED blanche L1 L2

- [x] 2x Résistance 380Ω (sous 5v — Vf=3.2v - 4.7mA/led). _Ref: R1 R2_

- [x] 3x LEDs oranges (pour les Modes). Prévoir 2 à 3 cd (20 à 30 lumen). _Ref: L3 L4 L5_  
  LED Orange
  
- [x] 1x LED verte (pour l'info Bluetooth BT). _Ref: L6_  
  LED Orange
  
- [ ] 4x Résistance 150Ω (sous 3.3v — Vf=2.1v, 8mA/led). _Ref: R3 R4 R5 R6_

- [x] 5x LED 3mm vert-jaune (pour le rating). _Ref: L11 L12 L13 L14 L15_
  Leds pour rating

- [x] 1x LED 3mm mauve (pour le bat). _Ref: L16_
  Led pour beat

- [] 6x Résistance 200Ω (sous 3.3v — Vf=2.2v, 5.5mA/led). _Ref: R11 R12 R13 R14 R15 R16_  
  Résistances 200Ω

- [x] 2x LEDs E10 (Eclairage tuning). _Ref: L20 L21_   
  Ampoule incandescente 6V/0.25W — sans résistance (filament auto-limitant, ~34mA sous 5v).  
  LED E10 amber L3 L4

### Inputs

- [x] 4x PushButton (Year / Genre / Beat / Bluetooth). _Ref: B1 B2 B3 B4_  
  PushButton modes
  
- [x] 3x PushButton (Again / Star me / Next). _Ref: B5 B6 B7_  
  PushButton x3
  
- [x] 8x Résistance pull-up 10kΩ SIL-9 (7 utilisées + 1 spare). _Ref: RS1_  
  SIL-9 10k

- [x] 1x micro PushButton (Reset database) - En face arrière. _Ref: SW1_  
  PushButton Reset DB
  
- [x] 1x Résistance 20kΩ pull-up. _Ref: R31_

- [x] 1x Switch Button (Local files/DLNA) - En face arrière. _Ref: SW2_  
  Switch Local/DLNA
  
- [x] 1x Résistance 20kΩ pull-up. _Ref: R32_

- [x] 1x Power Button (incl. LED) - En face arrière. Bouton 16mm chrome, anneau LED bleue. _Ref: SW3_  
  Power Button
  
- [x] 1x Résistance 120Ω (LED ring bleue, sous 5v — Vf=3.2v, 15mA). _Ref: R33_

### Composants

- [x] Amplificateur audio (mono)
   InnoMaker RPI HiFi AMP Hat TAS5713 Amplifier Audio Module 25W Class D Power.  
   Sound Card Extension Board for Raspberry Pi 5/4/3/B+/Pi/Zero.  
   Capacitor Nichicon. Connexion SPI. Sortie sur connecteur. Réglage du gain.  
   Power supply = 12/20v.  
   36€ Amazon.  
  InnoMaker TAS5713
  InnoMaker TAS5713 HAT  
  [Pinout](datasheets/InnoMaker_TAS5713_pinout.jpg) — [Board map](datasheets/InnoMaker_TAS5713_map.jpg)

- [x] 74HC595 Registres à décalage pour controle des LEDs. Format DIP-16.   
   Amazon 9€ (les 10).  
  74HC595  
  [Pinout](datasheets/SN74HCS595_Pinout.png)

- [x] PCF8575 (16-Inputs) I2C Expander pour controle des Pushbutton. Format miniboard.   
   Amazon 7€ (les 2)
  PCF8575 front 
  PCF8575 back  
  [Datasheet](datasheets/PCF8575.md)

- [x] MCP3008 Convertisseur analogique-numerique Adafruit (ADC).  Format DIP-16.  
   8 canaux, 10 bits (1024 valeurs) - Connexion SPI. Lib Python: spidev.    
   Amazon 22€ (les 2).  
  MCP3008  
  [Datasheet](datasheets/MCP3008-Converter.md)
	
- [x] Potentiomètre 10kΩ - linéaire A. _single-turn_.  
	
- [x] Potentiomètre 10kΩ - linéaire A - Avec interrupteur.  

- [ ] Ecran plexi

### Connectique

- [ ] Header 40 double row for Raspberry extension board

### Récapitulatif des résistances

  | Valeur     | Qté       | Refs                        | Usage                       | En stock |
  | ---------- | --------- | --------------------------- | --------------------------- | -------- |
  | 120Ω       | 2         | R0, RP                      | L0 (témoin) + POW (ring)    | oui      |
  | 150Ω       | 4         | R21 R22 R23 R24             | M1–M4 (mode superamber)     |          |
  | 200Ω       | 7         | R11 à R17                   | V1–V7 (LED bar rating)      | oui      |
  | 380Ω       | 2         | R1 R2                       | L1 L2 — backlight ePaper    | oui      |
  | 10kΩ SIL-9 | 1 boîtier | RS1                         | B1–B7 (7 pull-ups, 1 spare) | oui      |
  | 20kΩ       | 2         | R31 R32                     | B8 Reset + SW9 Local/DLNA   | oui      |

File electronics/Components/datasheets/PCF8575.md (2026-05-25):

# Hailege  PCF8575 IO Expansion Board 

## Description du produit

Vous n’avez plus de broches d’E/S ? Ce module permet à l’utilisateur d’étendre jusqu’à 16 E/S avec seulement deux E/S pour le contrôle ! Le PCF8575 est contrôlé via une interface I2C et dispose de broches d’entrée/sortie quasi-bidirectionnelles de 16 bits. Si vous ne soudez pas le pad VCC-VDD, le niveau PCF8575 est de 3,3 V. Si vous le soudez, le niveau est le même au VCC.

## Caractéristiques :

- Puce principale : PCF8575

- Tension de fonctionnement : 2,5 - 5,5 V DC

- Courant de fonctionnement : 100 mA (MAX)

- Adresse I2C : 0x20 (standard), peut être remplacée par soudure des pavés de sélection A1 et A2

- 16 broches adressables individuellement.  
  Chaque broche peut être configurée pour l’entrée ou la sortie.

- Goupille de sortie d’interruption à drain ouvert pour l’interruption de changement d’entrée.

Idéal pour UNO R3 et d’autres microcontrôleurs pour contrôler des relais simples, des buzzers, des boutons, des LED, etc.

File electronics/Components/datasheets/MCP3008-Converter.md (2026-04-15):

# Vintage Radio

## Convertisseur analogique-numerique (ADC)

MCP3008 (SPI) : 8 canaux, 10 bits (1024 valeurs). 

MCP3008 - 8-Channel 10-Bit ADC With SPI Interface.

Simple à câbler.
Vibliothèque Python (spidev).  
Adafruit:  5€  [Product ID: 856]
	
Role: interfacàage avec un potentiomètre analogique.  
(il n'y a pas d'entrée analogique sur un Raspberry).

###  Schéma de principe

```  
  Potentiomètre 10kΩ          MCP3008              Raspberry Pi
┌─────────────┐           ┌──────────┐          ┌──────────────┐
│  Broche 1 ──┴── GND     │ VSS (1)  │──────────┴── GND        │
│  Broche 2 ──┬── CH0 (1) │ VREF (2) │──────────┴── 3.3V       │
│  Broche 3 ──┴── 3.3V    │ AGND (3) │──────────┴── GND        │
└─────────────┘           │ DGND (4) │──────────┴── GND        │
                          │ VDD (5)  │──────────┴── 3.3V       │
                          │ DVDD (6) │──────────┴── 3.3V       │
                          │ CLK (7)  │──────────┴── GPIO 23 (SCLK)
                          │ DOUT (8) │──────────┴── GPIO 24 (MISO)
                          │ DIN (9)  │──────────┴── GPIO 25 (MOSI)
                          │ CS (10)  │──────────┴── GPIO 8 (CE0)
                          └──────────┘          └──────────────┘
```

### Activation du SPI

```shell
sudo raspi-config
# Aller dans : Interface Options -> SPI -> Yes
sudo apt-get install python3-spidev						  
```

###  Cablage

- Alimentation (Power):
   - **3.3V** : Relié aux broches `VDD`, `DVDD`, `VREF` du MCP3008 et à la broche 3 du potentiomètre.
   - **GND** : Relié aux broches `VSS`, `AGND`, `DGND` du MCP3008 et à la broche 1 du potentiomètre.

- Signal Analogique:
   - **Data** : La broche centrale du potentiomètre (Broche 2) va sur `CH0` (Canal 0) du MCP3008.

Interface SPI (Communication):

| ------  | --- | --- | --- |
| Signal  | MCP3008 (Slave) | Raspberry (Master) | SPI |
| Horloge | `CLK` | ↔ `GPIO 23` | SCLK| 
| Données du MCP vers le Pi | `DOUT` | ↔ `GPIO 24` | MISO| 
| Données du Pi vers le MCP | `DIN`  | ↔ `GPIO 25` | MOSI| 
| Chip Select | `CS` | ↔ `GPIO 8` | CE-0| 

```mermaid
graph LR
    subgraph Potentiometre_10k [Potentiomètre 10kΩ]
        P1[Broche 1<br/>GND]
        P2[Broche 2<br/>Signal]
        P3[Broche 3<br/>3.3V]
    end

    subgraph MCP3008 [Convertisseur ADC MCP3008]
        direction TB
        VSS[VSS<br/>GND]
        VREF[VREF<br/>3.3V]
        AGND[AGND<br/>GND]
        DGND[DGND<br/>GND]
        VDD[VDD<br/>3.3V]
        DVDD[DVDD<br/>3.3V]
        CLK[CLK<br/>Horloge]
        DOUT[DOUT<br/>Données Sortie]
        DIN[DIN<br/>Données Entrée]
        CS[CS<br/>Sélection]
        CH0[CH0<br/>Canal 0]
    end

    subgraph Raspberry_Pi [Raspberry Pi GPIO]
        GND_PI[GND<br/>Pin 6/9/14...]
        V33[3.3V<br/>Pin 1/17]
        SCLK[SCLK<br/>GPIO 23<br/>Pin 16]
        MISO[MISO<br/>GPIO 24<br/>Pin 18]
        MOSI[MOSI<br/>GPIO 25<br/>Pin 22]
        CE0[CE0<br/>GPIO 8<br/>Pin 24]
    end

    %% Connexions Alimentation & Masse
    P1 --- GND_PI
    P3 --- V33
    
    VSS --- GND_PI
    AGND --- GND_PI
    DGND --- GND_PI
    
    VREF --- V33
    VDD --- V33
    DVDD --- V33

    %% Connexions Signal
    P2 --- CH0

    %% Connexions SPI
    CLK --- SCLK
    DOUT --- MISO
    DIN --- MOSI
    CS --- CE0

    %% Styles
    style Potentiometre_10k fill:#f9f,stroke:#333,stroke-width:2px
    style MCP3008 fill:#bbf,stroke:#333,stroke-width:2px
    style Raspberry_Pi fill:#bfb,stroke:#333,stroke-width:2px
	
```

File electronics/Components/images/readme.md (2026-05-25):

# Vintage Radio

## Component images

Images ou photos des différents composants.

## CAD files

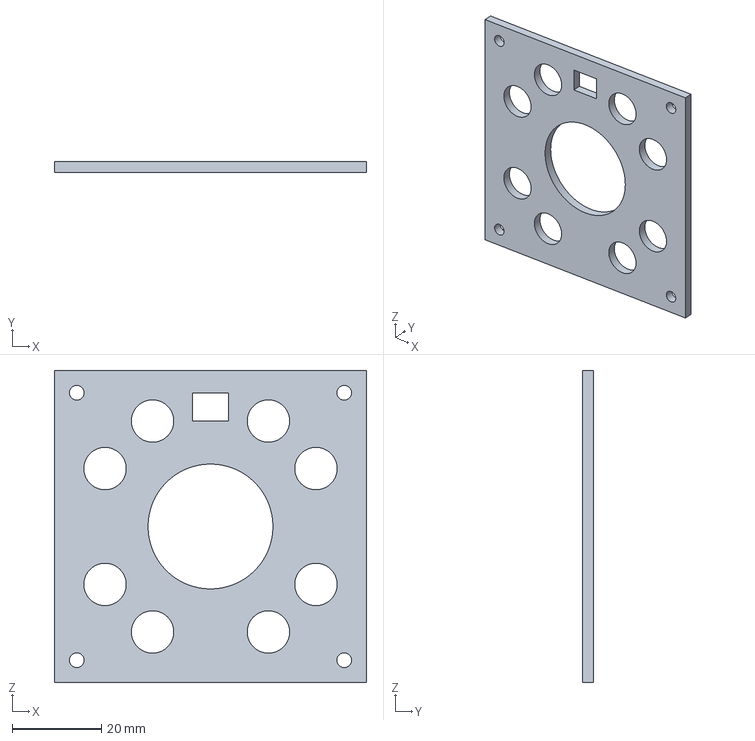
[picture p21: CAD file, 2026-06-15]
mechanical/3mf/VintageRadio-Support_Leds_E10.3mf
70.0 x 2.50 x 70.0 mm

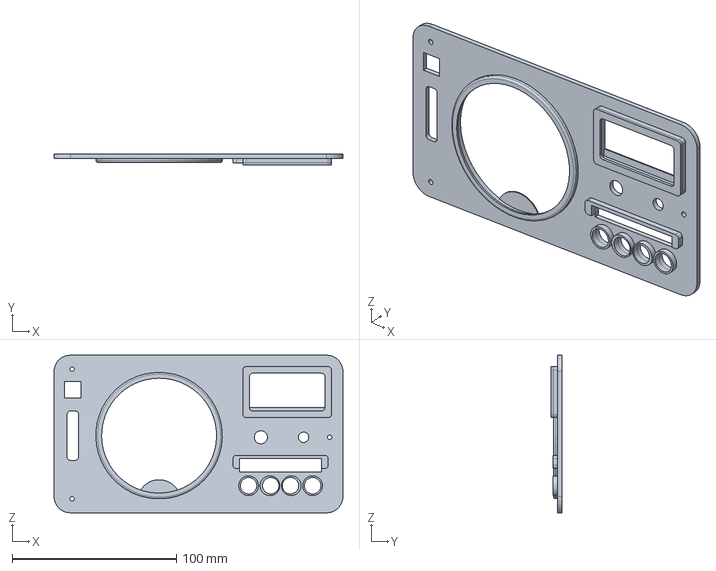
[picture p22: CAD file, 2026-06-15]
mechanical/cad/VintageRadio.FCStd
176.0 x 6.50 x 96.0 mm

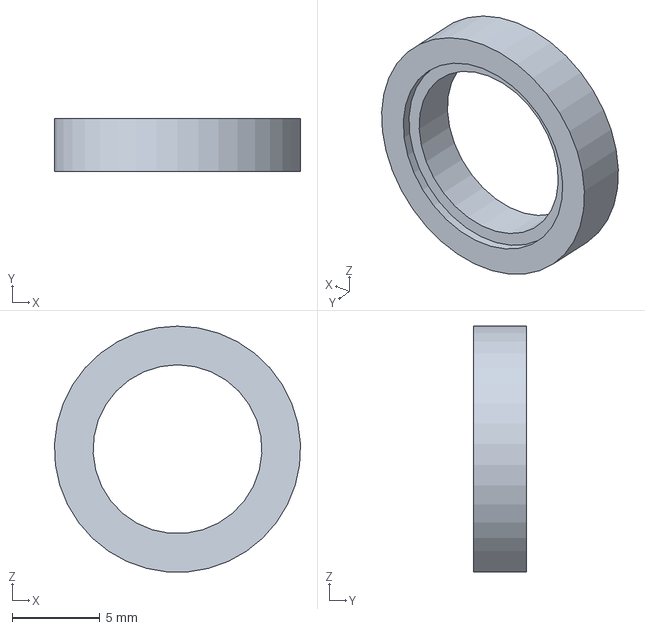
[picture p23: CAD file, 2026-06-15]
mechanical/3mf/VintageRadio-Rondelle_LED.3mf
14.0 x 3.00 x 14.0 mm

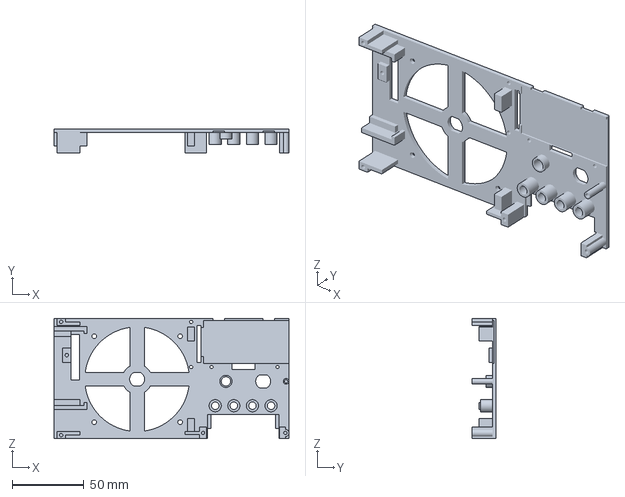
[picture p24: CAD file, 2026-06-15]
mechanical/3mf/VintageRadio-Support.3mf
164.0 x 17.0 x 84.0 mm

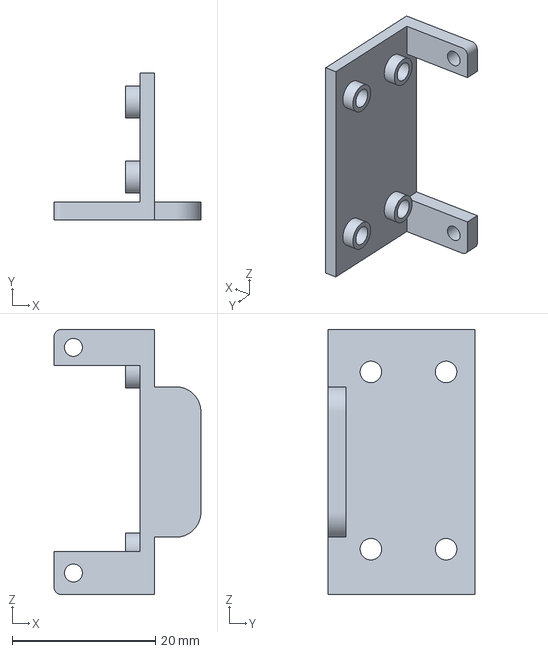
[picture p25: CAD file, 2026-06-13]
mechanical/3mf/VintageRadio-Support_ePaper-1.3mf
20.5 x 20.5 x 37.0 mm

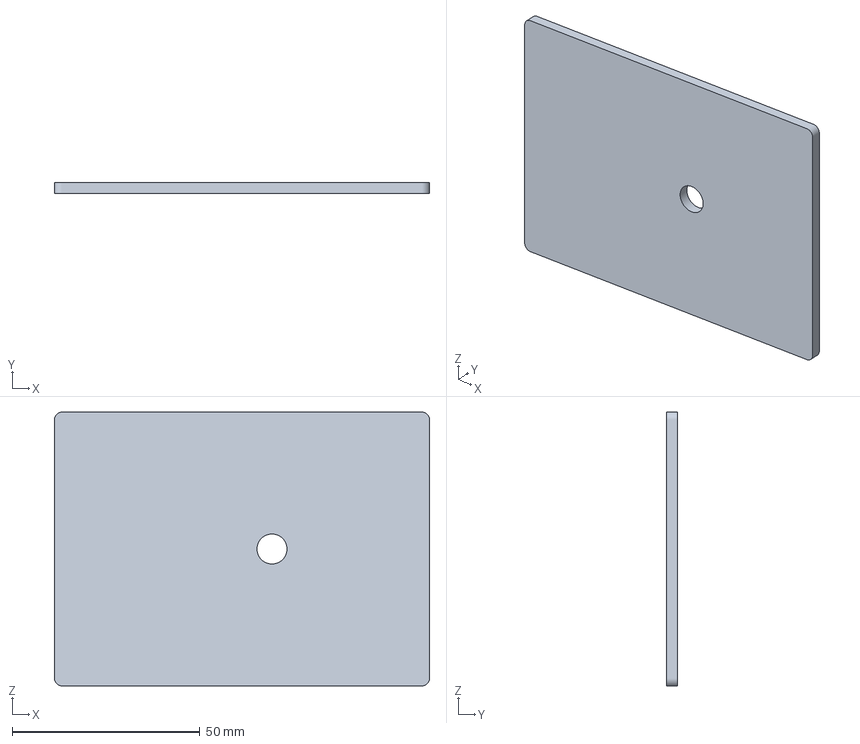
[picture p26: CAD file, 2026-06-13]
mechanical/3mf/VintageRadio-Plexi.3mf
100.0 x 3.00 x 73.0 mm

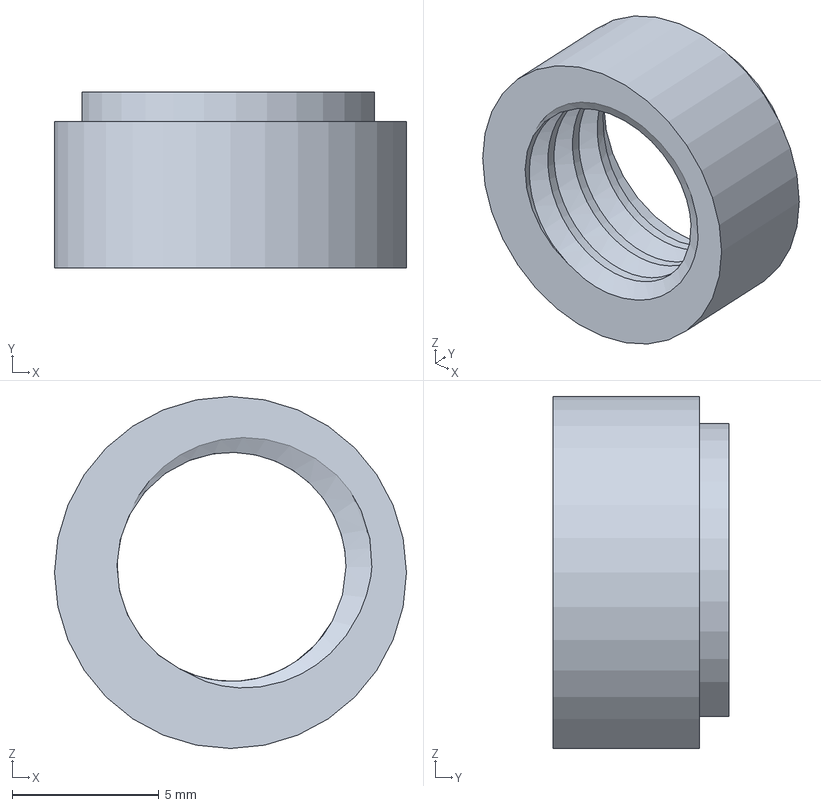
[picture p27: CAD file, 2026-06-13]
mechanical/3mf/VintageRadio-Bouchon_LED.3mf
12.0 x 6.00 x 12.0 mm

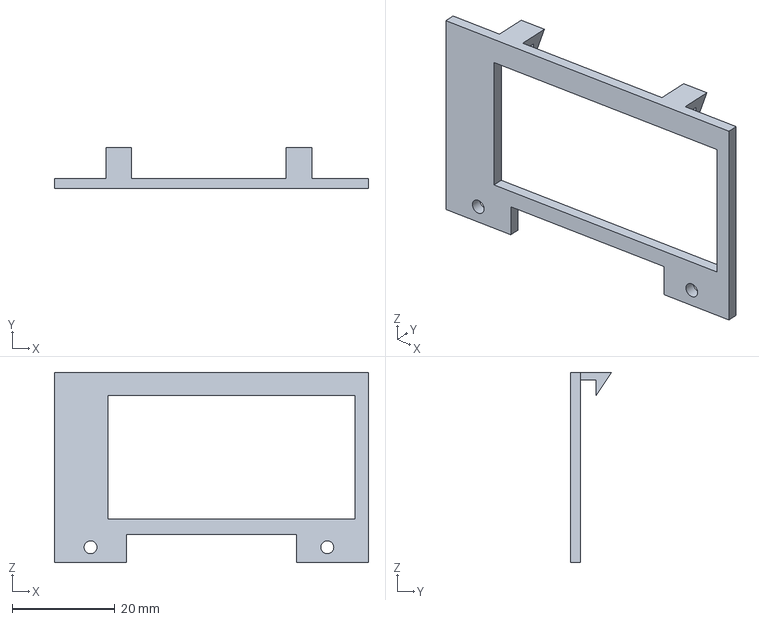
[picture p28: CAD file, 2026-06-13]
mechanical/3mf/VintageRadio-Support_ePaper-3.3mf
61.0 x 8.00 x 37.0 mm

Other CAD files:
mechanical/3mf/VintageRadio-Face_Avant.3mf

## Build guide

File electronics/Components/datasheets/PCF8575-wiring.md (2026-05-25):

# PCF8575 — Câblage I2C et boutons

## Principe

Un module PCF8575 sur le bus I2C.  
Chaque module a une adresse distincte configurée par ses broches A0/A1/A2.

| Module | A0  | A1  | A2  | Adresse I2C |
| --- | --- | --- | --- | --- |
| #1 | GND | GND | GND | 0x20 |

Le PCF8575 dispose de 16 I/O (P00–P07 + P10–P17). 

## Exeple de schéma

```mermaid
graph TD

    RPI["🖥 Raspberry Pi\nGPIO SDA / SCL\n(I2C bus)"]

    subgraph PCF1["PCF8575 #1 — 0x20\n(A0=A1=A2=GND)"]
        direction LR
        SDA1["SDA"] & SCL1["SCL"]
        P00["P00"] --- B1["B1 — Year"]
        P01["P01"] --- B2["B2 — Genre"]
        P02["P02"] --- B3["B3 — Beat"]
        P03["P03"] --- SW4["SW4 — Bluetooth"]
        P04["P04"] --- B5["B5 — Again"]
        P05["P05"] --- B6["B6 — Star me"]
        P06["P06"] --- B7["B7 — Next"]
        P07["P07"] --- B8["B8 — Reset DB"]
        P10["P10"] --- SW9["SW9 — Local/DLNA"]
        P11["P11–P17 (libres)"]
    end

    subgraph PCF2["PCF8575 #2 — 0x21\n(A0=VCC, A1=A2=GND)"]
        direction LR
        SDA2["SDA"] & SCL2["SCL"]
        P20["P00–P17 (libres — extension)"]
    end

    RPI -- "SDA" --> SDA1 & SDA2
    RPI -- "SCL" --> SCL1 & SCL2
```

## Câblage des boutons

Chaque bouton est câblé entre la broche I/O du PCF8575 et **GND**.  
La résistance pull-up (RS1 = SIL-9 10kΩ, ou R31/R32 = 20kΩ) tire la broche
vers **3.3V** au repos. L'appui tire vers GND → lecture LOW = appuyé.

```
3.3V ──┬── [10kΩ] ──┬── PCF8575 Pxx
       │            │
       │         [Bouton]
       │            │
      GND          GND
```

## Code Python (lecture)

```python
import smbus2

bus = smbus2.SMBus(1)

# Lire les 16 pins du chip #1 (2 octets : port0, port1)
data = bus.read_i2c_block_data(0x20, 0, 2)
port0, port1 = data[0], data[1]

# Exemple : tester B1 (P00, bit0 de port0)
if not (port0 & 0x01):   # LOW = bouton appuyé
    print("B1 Year appuyé")
```

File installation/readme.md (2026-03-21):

# Vintage Radio - Installation

## Développement

Développement en Python.

- Sous Windows, utilisation de PyCharm
- appliquer les modules `python vlc` et `mutagen` dans l'environnement virtuel.
- Utilise la librairie Python `libvlc.dll`.
- Ajouter la DLL de VLC au path
   `setx Path "%Path%;C:\Program Files\VideoLAN\VLC"`

## Première installation sur Raspberry Pi

- Installation:
```bash
sudo apt update
sudo apt install python3-pip python3-vlc 
sudo apt install python3-mutagen
sudo apt install pulseaudio pulseaudio-utils pavucontrol
pip3 install -r requirements.txt   # (optional, if you add extra deps)
git clone https://github.com/Sphinkie/VintageRadio
...
# update with:
git pull
...
# run with
cd Programmes/VintageRadio
python VintageRadio.py
```

## Démarrage automatique Raspberry

### Installation

- Copier le fichier dans `/etc/systemd/system/vintageradio.service`.

- S'assurer d'avoir la dernière version du programme (`git pull`).

### Activer et démarrer le service

```bash
# Recharger la configuration systemd
sudo systemctl daemon-reload

# Activer le démarrage automatique au boot
sudo systemctl enable vintageradio.service

# Démarrer immédiatement (optionnel)
sudo systemctl start vintageradio.service
```

### Vérifier le statut

```bash
# Voir si le service tourne
sudo systemctl status vintageradio.service

# Voir les logs
sudo journalctl -u vintageradio.service -f
```

### Arrêter/Démarrer le service manuellement

```bash
sudo systemctl stop vintageradio.service
sudo systemctl start vintageradio.service
sudo systemctl restart vintageradio.service
```

### Modes de redémarrage

Options de Restart

- `no (défaut)` :	Ne redémarre jamais. Pour services one-shot, tâches ponctuelles...
- `on-success` :	Redémarre uniquement si le processus sort avec code 0. Pour les scripts qui doivent s'exécuter à nouveau après succès.
- `on-failure` :	Redémarre si exit code ≠ 0, signal, ou timeout (évite les boucles infinies).
- `on-abnormal` :	Redémarre sur signaux, timeout, watchdog. Pour les services critiques qui ne doivent pas planter silencieusement.
- `on-watchdog` :	Redémarre uniquement sur timeout watchdog. Pour les services avec surveillance matérielle/logicielle.
- `on-abort` :	Redémarre uniquement sur signaux (SIGTERM, SIGINT, etc.). Pour les services qui doivent survivre aux interruptions.
- `always` :	Redémarre dans tous les cas (redémarre même après CTRL-C).

### Autres paramètres utiles

```ini
[Service]
# Délai entre les redémarrages (évite les boucles rapides)
RestartSec=10

# Limite le nombre de redémarrages (optionnel)
StartLimitBurst=5
StartLimitIntervalSec=60

# Arrêt propre avec timeout
TimeoutStopSec=30

# Signaux envoyés à l'arrêt
KillSignal=SIGTERM
KillMode=mixed
```

## Recommandations Lumo

- **VLC** :	Assurez-vous que `python3-vlc` est installé et accessible.
- **Audio** :	Configurez la sortie audio par défaut dans `/boot/config.txt` si nécessaire.
- **Logs** :	Utilisez `journalctl -u vintageradio.service` pour déboguer.
- **Arrêt propre** :	Le service *systemd* gère le signal SIGTERM, mais votre code doit gérer SIGINT (CTRL-C).

## Dossiers

- `pulse/system.pa` : ce fichier permet en théorie au module Son **Alsa** d'utiliser la librairie **pulseAudio** et de trouver les périphériques blutooth. 
   En pratique, on a configuré le module Son **PipeWire**, donc ce fichier ne sert pas.

- `pipewire/pipewire.conf.d/99-default-sink.conf` : ce fichier permet en théorie à **pipewire** de retrouver l'enceinte blutooth JLB et de se connecter dessus. 
   En pratique, ce fichier semble plutot poser problème, car quand il est présent, on ne peut plus se connecter à l'enceinte JLB.
   De plus, il n'est pas vraiment utile, car on peut configurer **pipewire** de façon perenne, via la ligne de commande:
   ```shell
   $ pactl set-default-sink bluez_output.20_18_5B_06_45_B0.1
   ```

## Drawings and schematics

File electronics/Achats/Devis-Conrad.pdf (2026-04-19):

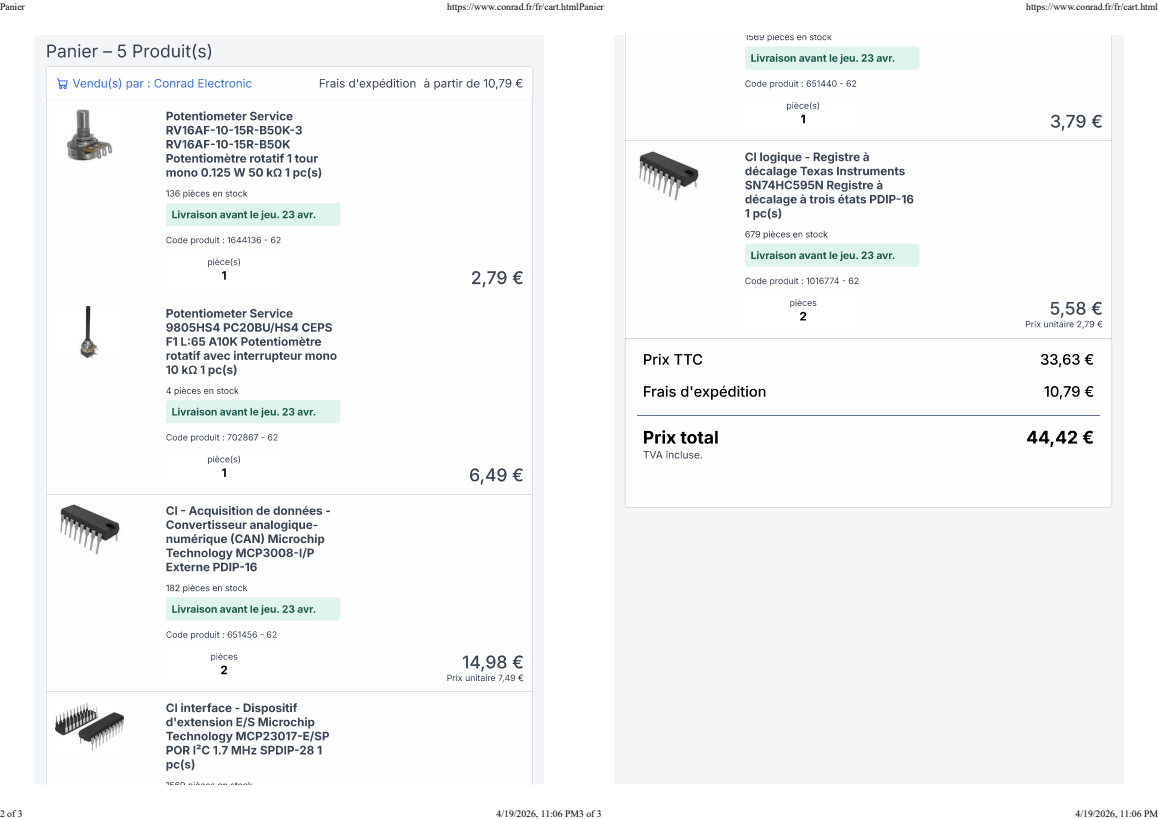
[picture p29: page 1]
Panier; https://www.conrad.fr/fr/cart.html

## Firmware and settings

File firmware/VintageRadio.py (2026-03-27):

# coding: UTF-8
# ==================================================================
# VintageRadio.py
# ==================================================================
# VintageRadio - Programme principal
# David de Lorenzo (2026)
# ==================================================================
import asyncio
import argparse
from lib.vr_logger import get_logger, set_logging
from lib.dlna_music import DLNAMusic
from lib.vr_engine import VREngine
from lib.user_request import UserRequest
from lib.user_keyboard import KeyboardController
import signal
import sys


# --------------------------------------------------------------------- #
# --------------------------------------------------------------------- #
def sigint_handler(signum, frame):
    print(f"Received SIGINT! (signum={signum} - frame={frame})")
    sys.exit(0)


# --------------------------------------------------------------------- #
# --------------------------------------------------------------------- #
def on_key_press(action):
    """ Callback for the Keyboard and GPIO Listening threads. """
    if action == 'QUIT':
        log.warning("QUIT command received")
    elif action == 'NEXT':
        log.info("PLAY NEXT command received")
        # La musique suivante va commencer automatiquement.
        musics.stop()
    elif action == 'AGAIN':
        log.info("PLAY AGAIN command received")
        musics.rewind()
        # La musique va recommencer automatiquement.
        musics.stop()
    elif action == 'RESET':
        log.info("RESET command received")
        # Supprime la base de données et quitte.
        # Utilisé si la BDD a besoin d'être rafraichie
        engine.drop_database()
        log.warning("Quit application")
        quit_event.set()
    elif action == 'DISCOVER':
        log.info("DISCOVERY command received")
        # Refait un scan du réseau à la recherche de serveurs DLNA
        # Utilisé pour la mise au point
        engine.net_wrapper.discover_servers()
    # TODO : action STAR ME


# --------------------------------------------------------------------- #
# --------------------------------------------------------------------- #
def parse_args() -> argparse.Namespace:
    """
    # Helper pour le programme principal.
    # Parsing des arguments en ligne de commande.
    :return: La liste des arguments.
    """
    parser = argparse.ArgumentParser(
        description='VintageRadio - DLNA Music Player for Raspberry Pi'
    )
    # Parse command-line arguments.
    parser.add_argument(
        '-v', '--verbose',
        action='count',
        default=0,
        help='Increase verbosity (-v for INFO, -vv for DEBUG)'
    )
    return parser.parse_args()


# --------------------------------------------------------------------- #
# --------------------------------------------------------------------- #
def setup():
    """ Setup() : Main initialisation procedure. """
    log.info("Start Setup")
    # -----------------------------------------------------------------
    # Get the DLNA server
    # -----------------------------------------------------------------
    engine.get_dlna_server()
    # -----------------------------------------------------------------
    # Récupère la liste de tous les MP3 du serveur DLNA
    # -----------------------------------------------------------------
    engine.scan_all_mp3()
    # -----------------------------------------------------------------
    # Première lecture du fichier de demande
    user_request.load_user_request()
    # Lance le Listener du clavier dans un thread.
    keyboard_ctrl.start()
    # -------------------------------------------------------------
    log.info("End Setup")


# --------------------------------------------------------------------- #
# --------------------------------------------------------------------- #
async def loop():
    """ loop() : Boucle principale asynchrone. """
    log.debug("Start Loop")
    lecture_task = None
    # ------------------------------------------------------------------------
    # Tache périodique No 1 : Reload user request (json file) every 5 seconds.
    # ------------------------------------------------------------------------
    refresh_task = asyncio.create_task(user_request.repeating_reread(5))  # fire-and-forget
    # ------------------------------------------------------------------------
    # Tache périodique No 2 : Read missing Beat Per Minute and Ratings on server.
    # ------------------------------------------------------------------------
    refresh_bpm = asyncio.create_task(engine.repeat_get_data(6))  # start repeating

    try:
        # --------------------------------------------------------------------
        # Boucle principale
        # --------------------------------------------------------------------
        while True:
            # ----------------------------------------------------------------
            # [1] Check if a QUIT event was received
            # ----------------------------------------------------------------
            if quit_event.is_set():
                log.debug("Exiting loop")
                break

            # ----------------------------------------------------------------
            # [2] A-t-on une nouvelle requete de l'utilisateur ?
            # ----------------------------------------------------------------
            if user_request.has_changed():
                log.info("User request change detected")
                # -------------------------------------------------------------
                # List the MP3 files for the request, and send them to the Music object.
                # -------------------------------------------------------------
                log.info(f"Current requested Mode is 'by {user_request.get('mode')}'")
                log.info(f"Current Request is '{user_request.get('request')}'")
                track_list = engine.get_tracklist_from_db(user_request.get('mode'), user_request.get('request'))
                musics.load_playlist(track_list)
                # En cas de playlist par genre ou par rating, on la met dans un ordre aléatoire
                # (chaque fois différent).
                if user_request.get('mode') == 'genre' or user_request.get('mode') == 'rating':
                    musics.shuffle_playlist()
                else:
                    musics.clone_playlist()
                # musics.list_all()
                # On acquitte la prise en compte du changement.
                user_request.ack_has_changed()

            # -------------------------------------------------------------
            # [3] Play MP3 files
            # -------------------------------------------------------------
            if lecture_task is None:
                log.debug("Start playing a new file")
                lecture_task = asyncio.create_task(musics.play_async())
                # On attend que la lecture ait démarré
                await lecture_task
                # On demande l'affichage du titre
                current_id = musics.get_playing_id()
                display_task = asyncio.create_task(engine.show_clip_info(current_id))
                log.debug(f"Start task {display_task}")
            # -------------------------------------------------------------
            # [4] Check if the MP3 file is still playing
            # -------------------------------------------------------------
            else:
                if musics.is_stopped():
                    lecture_task = None
                    log.debug("End playing]")
            # --------------------------------------------------------------------
            # [5] Boucle rythmée à 1 seconde.
            # --------------------------------------------------------------------
            await asyncio.sleep(1)
    # --------------------------------------------------------------------
    # Sortie de la boucle: on ferme tout.
    # --------------------------------------------------------------------
    finally:
        log.warning("End loop")
        keyboard_ctrl.stop()
        refresh_task.cancel()
        refresh_bpm.cancel()
        # On attend que les tâches s'achèvent
        await refresh_task
        await refresh_bpm
        log.warning("Shutdown complete")


# --------------------------------------------------------------------- #
# --------------------------------------------------------------------- #
async def main():
    """ PROGRAMME PRINCIPAL """
    # -----------------------------
    # On exécute le Setup
    # -----------------------------
    setup()
    # -----------------------------
    # On lance la boucle (si on a un serveur DLNA)
    # -----------------------------
    if engine.ready():
        await loop()
    engine.close()


# --------------------------------------------------------------------- #
# Launch Main Program (EventLoop)
# --------------------------------------------------------------------- #
if __name__ == "__main__":
    args = parse_args()
    # ---------------------------------------------------------
    # Initialisation du logger
    # ---------------------------------------------------------
    set_logging(args.verbose)
    log = get_logger(__name__)
    # ---------------------------------------------------------
    # Initialisations des objets
    # ---------------------------------------------------------
    engine = VREngine()
    musics = DLNAMusic()
    user_request = UserRequest()
    # ---------------------------------------------------------
    # Initialise le Keyboard Listener thread
    # ---------------------------------------------------------
    signal.signal(signal.SIGINT, sigint_handler)
    # Create a Quit Event
    quit_event = asyncio.Event()
    keyboard_ctrl = KeyboardController(on_key_press, quit_event)
    # ---------------------------------------------------------
    # Lancement de l'Event Loop
    # ---------------------------------------------------------
    asyncio.run(main())

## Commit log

2026-03-06 Enhance README with usage tips for Raspberry and Windows
    Added tips for using VintageRadio on Raspberry Pi and Windows.
2026-03-06 feat: Ajout de Random Play
2026-03-06 feat: fichier JSON pour la requète utilisateur
2026-03-07 Utilisation de logger.debug()
2026-03-07 Ajout de dlna_logger
    WIP : rendre PLAY non bloquant
2026-03-08 Mise en place de la boucle principale.
2026-03-09 Capture des touches clavier
2026-03-10 fix : DLNA non trouvé
    [VintageRadio.py]
2026-03-11 fix: micmac entre ctrl_url et desc_url
    [VintageRadio.py]
2026-03-11 fix: pb de terminal SSH
2026-03-11 fix: CR manquant dans les logs console sur Raspberry
2026-03-12 Simulation de l'afficheur
2026-03-12 Ajout des options -h -v et -vv
2026-03-12 wip : extraction des tags ID3
2026-03-16 Stockage title et artist dans la database
2026-03-18 Pas de clavier en mode daemon linux
2026-03-18 Sortie son ALSA (au lieu de PULSE)
2026-03-18 Reutilisation de l'instance VLC
2026-03-21 Fix: daemon mode with bluetooth speaker !
    Essai des modules audio asla, pulse, puis pipewire...
    OK avec pipewire.
    [VintageRadio.py]
2026-03-22 Gestion du critère de sélection par année/décade (YEAR)
2026-03-22 Ajout de l'aléatoire dans l'ordre des clips (par année)
2026-03-24 recupération des BPM en http
2026-03-25 Implementation de reset database
    [VintageRadio.py]
2026-03-26 Jouer les morceaux en fonction du critère BPM (BEAT)
2026-03-27 fix : "stars" in rating number
    [VintageRadio.py]
2026-04-14 Fix formatting and improve clarity in Bill of Materials
    Correct formatting and enhance clarity in the Bill of Materials for MCP3008 and associated components.
2026-04-14 Fix formatting and clarify Potentiometer section
    Corrected formatting and improved clarity in the Bill of Materials.
2026-04-14 Refactor hardware docs: Amplifier & BOM
2026-04-15 Bill Of Material
2026-04-19 update devis
    [BOM_VintageRadio.xlsx]
2026-05-24 Résistances : documentation complète et mise à jour BOM
    - Ajout de hardware/Resistances.md : tableau complet des résistances LEDs
    (On, P, L1-L4, V1-V7, M1-M4) avec Vf et mA calculés, et section
    boutons poussoirs (pull-up 10kΩ via PCF8574)
    - BOM : valeurs confirmées pour les résistances mode (150Ω), rating (150Ω),
    E10 tuning (150Ω), power ring (120Ω) ; section récapitulatif ajoutée
    - Ajout photo bouton power 16mm chrome anneau LED bleue
2026-05-24 Graphes de conception
2026-05-25 Résistances : valeurs finalisées et refs composants
    - Resistances.md : R17 corrigé 150Ω→200Ω (cohérence V1-V7),
    R31/R32 mis à jour 10kΩ→20kΩ (stock disponible)
    - BillOfMaterial.md : refs _Ref:_ ajoutées sur tous les composants,
    valeurs résistances corrigées (220Ω→200Ω LED bar, 10kΩ→20kΩ R31/R32),
    récapitulatif mis à jour avec colonne Refs
2026-05-25 Résistances : corrections L3/L4 et M4
    - L3/L4 (E10 amber) : suppression R3/R4 — ampoules incandescentes 6V
    auto-limitantes, pas de résistance nécessaire sous 5V
    - M4 : annulation LED pink (incompatible 3.3V), retour superamber 150Ω (R24)
    - BOM : récapitulatif 150Ω mis à jour qty 6→4 (R21–R24 uniquement)
2026-05-25 BOM : images et datasheets intégrés
    - Images PNG embarquées pour tous les composants couverts (LEDs, boutons,
    résistances, INNO, 74HC595, PCF8574, MCP3008)
    - Hyperliens vers les datasheets (INNO pinout/map, 74HC595 pinout,
    PCF8574, MCP3008, LED superambre)
2026-05-25 Components : réorganisation en sous-dossiers images/ et datasheets/
    - images/ : PNG nettoyés et renommés pour tous les composants
    - datasheets/ : fiches techniques déplacées (INNO pinout/map, MCP3008,
    PCF8575, 74HC595, LED superambre)
    - Suppression des anciens fichiers à la racine de Components/
2026-05-25 BOM : taille des images unifiée + README datasheets
    - BOM : images converties en <img width="150"> pour affichage uniforme
    - datasheets/readme.md : tableau avec hyperliens vers chaque document
2026-05-30 Model 3D - Face avant
    [BOM_VintageRadio.xlsx, VintageRadio-Support PLA.stl, VintageRadio.FCStd]
2026-05-31 Extention board update
    - ajout des connecteurs
    - répartition face avant / face arrière
    [VintageRadio-Support PLA.3mf]
2026-05-31 New 3D model : support panel
    [VintageRadio-Support PLA.3mf, VintageRadio-Support PLA.stl, VintageRadio-Support.stl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]
2026-05-31 Extension board update (top side buttons)
2026-05-31 Support panel 3D model
    [VintageRadio-FaceAvant.stl, VintageRadio-Support PLA.3mf, VintageRadio-Support.stl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]
2026-05-31 Bouchon pour LED L0
    [VintageRadio-Cut.stl, VintageRadio.FCStd]
2026-06-01 3D models updates
    [VintageRadio-Bouchon_LED.stl, VintageRadio-Rondelle_LED.stl, VintageRadio-Support.stl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]
2026-06-01 Ajout ePaperDriverHAT
    [VintageRadio.FCStd]
2026-06-01 3D models README avec galerie d'images
    [VintageRadio.FCStd]
2026-06-02 3µD model : support ePaper
    [VintageRadio.FCStd]
2026-06-05 Supports pour ePaper
    [VintageRadio-Support_ePaper-1.stl, VintageRadio-Support_ePaper-2.stl, VintageRadio-Support_ePaper-3.stl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]
2026-06-05 correction encoches fixations ePaper
    [VintageRadio.FCStd]
2026-06-08 update 3D models
    [VintageRadio-Face avant.stl, VintageRadio-Support.stl, VintageRadio-Support_ePaper-3.stl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]
2026-06-09 Update hardware requirement
    [VintageRadio.FCStd]
2026-06-09 update hardware (LEDs)
2026-06-09 Réorganisation des dossiers hardware : hardware/ → electronics/, 3D models/ → mechanical/cad+stl/
    [VintageRadio-Bouchon_LED.stl, VintageRadio-Face_Avant.stl, VintageRadio-Rondelle_LED.stl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]
2026-06-09 Fixation des LEDs
    - Support
    - Bouchon LED
    [VintageRadio-Bouchon_LED.stl, VintageRadio-Support.stl, VintageRadio.FCStd]
2026-06-10 Trous de fixation pour Stripboard "modes"
    [VintageRadio-Face_Avant.stl, VintageRadio.FCStd]
2026-06-10 Maintien du plexiglass
    [VintageRadio-Face_Avant.stl, VintageRadio-Support.stl, VintageRadio.FCStd]
2026-06-11 Ajustement des trous de serrage
    [VintageRadio-Face_Avant.stl, VintageRadio-Support.stl, VintageRadio.FCStd]
2026-06-13 Passage au format 3mf
    [VintageRadio-Bouchon_LED.3mf, VintageRadio-Bouchon_LED.stl, VintageRadio-Face_Avant.3mf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]
2026-06-15 PLA models (Support LEDs E10)
    - Support LED E10 (nouveau)
    - Rondelle LED E10 (update profondeur)
    - Support (largeur entretoise)
    [VintageRadio-Rondelle_LED.3mf, VintageRadio-Support.3mf, VintageRadio-Support_Leds_E10.3mf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]
2026-10-29 circuit électronique
2026-11-03 connecteurs de 6 pins max
